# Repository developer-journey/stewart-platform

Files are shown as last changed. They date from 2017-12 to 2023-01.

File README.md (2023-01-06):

DISCONTINUATION OF PROJECT

This project will no longer be maintained by Intel.

Intel has ceased development and contributions including, but not limited to, maintenance, bug fixes, new releases, or updates, to this project.  

Intel no longer accepts patches to this project.

If you have an ongoing need to use this project, are interested in independently developing it, or would like to maintain patches for the open source software community, please create your own fork of this project.  
DISCONTINUATION OF PROJECT

This project will no longer be maintained by Intel.

Intel has ceased development and contributions including, but not limited to, maintenance, bug fixes, new releases, or updates, to this project.  

Intel no longer accepts patches to this project.

If you have an ongoing need to use this project, are interested in independently developing it, or would like to maintain patches for the open source software community, please create your own fork of this project.  
# Stewart platform source examples
Copyright (C) 2015-2017 Intel Corporation

## Overview

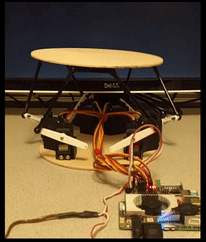
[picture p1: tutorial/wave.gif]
Do the Wave!


This directory provides **examples** that serve as supplimentary
material for the Developer Journey [1] to build a type of parallel 
robot called a Stewart platform [2].

1. https://01.org/developerjourney/stewart-platform
2. https://en.wikipedia.org/wiki/Stewart_platform

The examples contain software to:

* Communicate via i2c to a PCA9685
* Solve the Stewart platform to determine servo positions
* Utility functions for controlling the Stewat platform

To reduce dependencies, this program is not using MRAA to communicate
with the PCA9685.

## Stewart platform coordinate orientation

These routines work in a standaridzed world coordinate system (WCS)
where the XZ plane is the plane the Stewart platform is aligned to 
when no rotations are being performed (looking down on the Stewat 
platform.) The Y axis is aligned to the height of the Stewart platform 
axis (gravity).

The XZ plane is oriented such that the Z axis passes from between
servo 0|5 through the center of the platform (0, 0):

                                  z+
                                  ^
                                  |
                             .----+----.
                          2 /     |     \ 3
                           /      |      \
                        1 /       |(0,0,0)\ 4
                 x- <--- <--------+--------> ---> x+
                          \       |       /
                           \      |      /
                            \     |     /
                             `----+----'
                                0 | 5
                                  v
                    Top View      z-

## Building utilities

To build:

```bash
make
```

To test:
```bash
sudo bin/transform PITCH ROLL YAW X Y Z
```

For example:
```bash
sudo bin/transform 1 0 0  0 0 0
```

The above will rotate the platform one degree around the X axis.

## Piping data from STDIN

The `bin/transform` program can also read values from STDIN. When it
does so, however, it expects values to be provided in Axis-Angle form:

```bash
echo "0 1 0 3.5" | sudo bin/transform
```

The above will rotate the platform around the axis <0,1,0> by 3.5 degrees.

## Recording and playing back sequences

When piping data into transform, you can optionally record the sequence
of commands with timing information. You can then play that file back to
the application to repeat actions and movement sequences.

For example:
```bash
bin/joytrack /dev/input/js0 | bin/record MOVEMENTS | sudo bin/transform
```

You can then record a movement using your joystick (see the next section
for configuring a PlayStation 3 USB controller.) When you are done, 
press CTRL-C.

To play the file back:

```bash
bin/playback MOVEMENTS | sudo bin/transform
```

## Using a PS3 USB Controller

To use a PS3 USB controller to control the platform, you either need a
USB Bluetooth adapter or use it wired via the USB cable.

I have used the Rocketfish Micro USB Bluetooth adapter, which is 
supported in Ubuntu 16.04. You also need to pair the PS3 
controller with the system. You can follow the instructions here:

  http://qtsixa.sourceforge.net/manual.pdf

If you don't need/want to use the controller wirelessly, you can just
plug it into the USB port and open the joystick interface.

To do this, you only need the joystick package:

```bash
sudo apt install -y joystick
```

Once the PS3 controller is paired and recognized in the system (or if you
have any other joystick installed) you can use the program joytrack:

```bash
bin/joytrack /dev/input/js0 | sudo bin/transform
```

You can then control pitch and roll with left directional controller.

# Disclaimer

This project is released as reference code for research purposes. It is 
not an official Intel product, and the level of quality and support may 
not be as expected from an official product.

Feedback and contributions from the open source community are more than 
welcome.

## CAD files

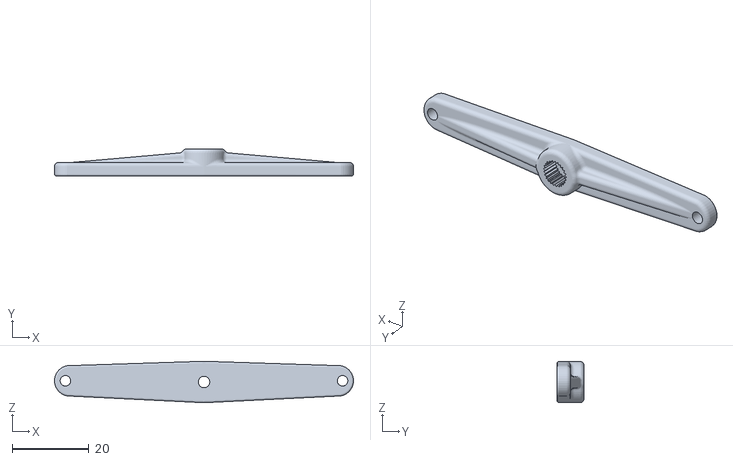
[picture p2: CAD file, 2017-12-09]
models/ServoArm.stl
78.0 x 7.00 x 10.8

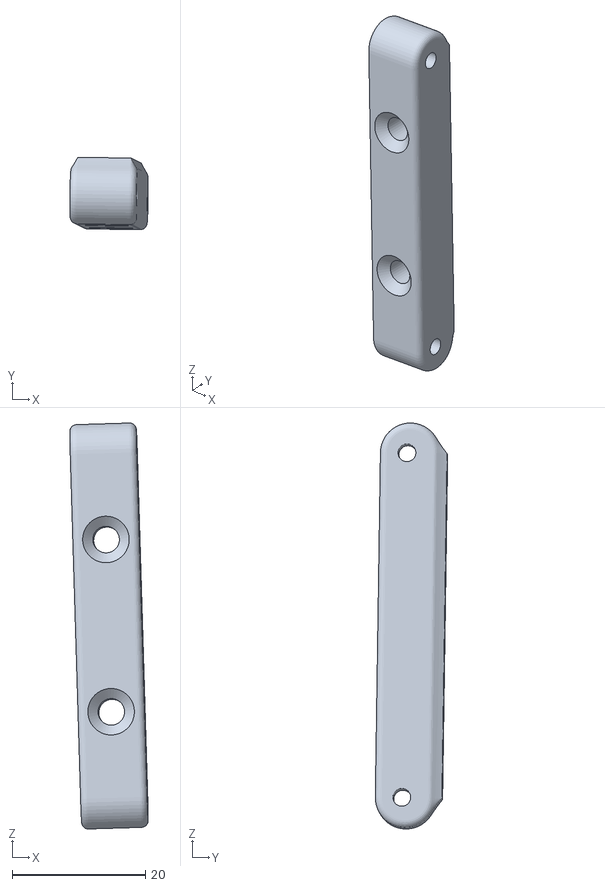
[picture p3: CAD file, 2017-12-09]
models/TopMount.stl
11.8 x 10.9 x 61.0

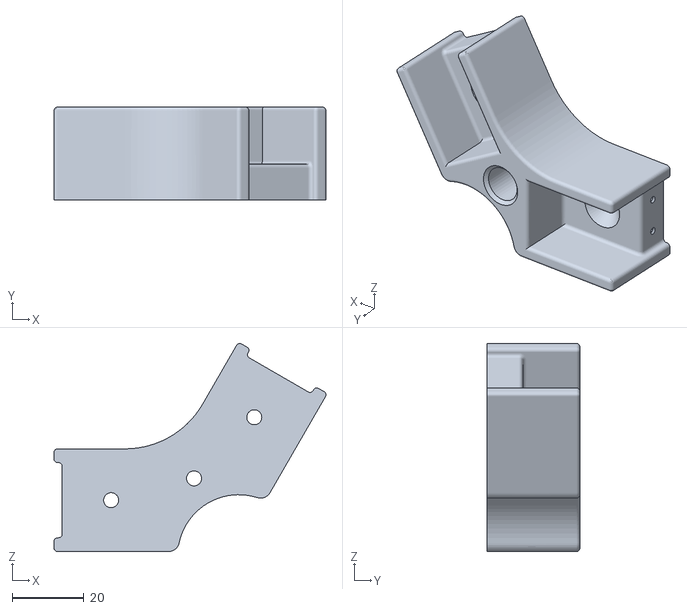
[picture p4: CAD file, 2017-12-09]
models/ServoMount.stl
76.0 x 26.0 x 58.2

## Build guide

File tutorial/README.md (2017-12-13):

---
title: Building a Stewart platform
author: James Ketrenos
license: cc-by-3.0
tags: robot, "stewart platform", "parallel robot"
---
# Introduction

Do the Wave!

Connecting the digital world to the physical world is exciting.

This guide provides you with the 3D models, information, and software to create your own Stewart platform.

## What is a Stewart platform?

Not familiar with a Stewart platform?

Stewart platforms have been used in vehicle and flight simulators, robotic skeleton assemblies, interactive marble maze solvers, and many other purposes.

A [Stewart platform](https://en.wikipedia.org/wiki/Stewart_platform) is a parallel robot with six degrees of freedom (6DOF).

The six degrees of freedom include movement in along three axis (X, Y, Z) as well as rotating in three directions (yaw, pitch, and roll.)

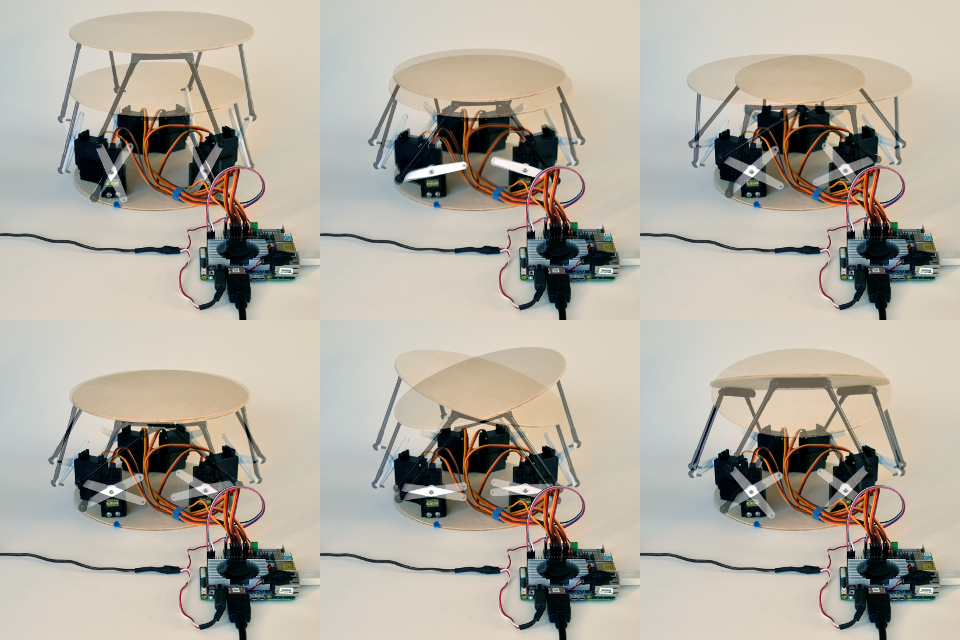
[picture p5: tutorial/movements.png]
Movement along Z, Y, and X axis. Rotation around Z-axis (Yaw), Y-axis (Pitch), and X-axis (Roll)


# Ingredients

Acquiring the parts is the most time consuming task. We've taken the guess work out by providing exact part descriptions and links to example products on the Internet.

There are three main categories of parts:

* The mechanical parts for the Stewart platform
* The electronics; wires, servos, breakout board
* The computer for controlling the Stewart platform

The total cost of all required parts, including the computer board, is ~$300US--having a 3D printer can save ~$66US.

## Mechanical parts

The mechanical parts needed for the Stewart platform include the top and bottom platforms, control rods to connect servos to the top platform, and the 3D printed components.

The total cost to acquire the mechanical parts is approximately $100US (only $34US if you print your own 3D printer.)

## Top and Base platform

| Qty | Name | Description | Est.$ |
|:---:|---|---|---|
|  2  | 8” MDF (or similar) wooden circles | Used as top and base plates. You can use a different size, however the board should be ⅛” ~ ¼” thick for rigidity and at least an 8” diameter [Amazon](https://www.amazon.com/gp/product/B00X6ATXHC) | $9 |
| 12  | M3 x 15mm Button Head Cap Screws (BHCS) | Helion HLNS1186 Button Head Cap Screws (BHCS) M3x15mm (10pcs) [Amazon](https://www.amazon.com/Helion-HLNS1186-Button-Screws-M3x15mm/dp/B01LXFZQ01) | $7 |
|  12 | #3 Phillips countersink screw with 8mm threading (10mm screw) | Used to connect control rod block and servo block platform boards. **NOTE**: Adjust the length of the countersunk screws to be the thickness of the MDF wooden circle + 5mm. If the screw is too long, it will stick through the wood; you can then grind/file the edge off. | $2 |

## Control rod components

| Qty | Name | Description | Est.$ |
|:---:|---|---|---|
| 12  | 10mm M3 threaded shaft (set screw) | Used to connect the ball joint to the connecting rod. [Amazon](https://www.amazon.com/RC4ZS0010-RC4WD-Threaded-Shafts-Screws/dp/B00A795L30) | $5 |
|  6  |65mm M3 aluminum standoff spacer|Used as the connecting rod. [Amazon](https://www.amazon.com/gp/product/B01NBXUD1E) | $5 |
| 12  |M3 straight ball joint|Pivot points between the connecting rods, the servos, and the platform. [Amazon](https://www.amazon.com/RC4WD-Medium-Straight-Plastic-Rod/dp/B009PBXIRW) | $5 |
| 12  |M3 lock nut (3/16" tall)|Used as a spacer between ball joints and mounted positions. You can also print spacers, or use washers, or anything you have that is ~3/16" thick. | $2 |

## 3D Printed Parts

There are a total of twelve parts to print. Three servo mounting blocks, six servo arms, and three top plate mounting brackets.

You can download and print the models yourselves, or print them via a 3rd party service. You can find 3D printers in your area via services like [Treat Stock](https://www.treatstock.com/3d-printable-models).

PLA is a sufficient material to use when printing.

### Servo mount

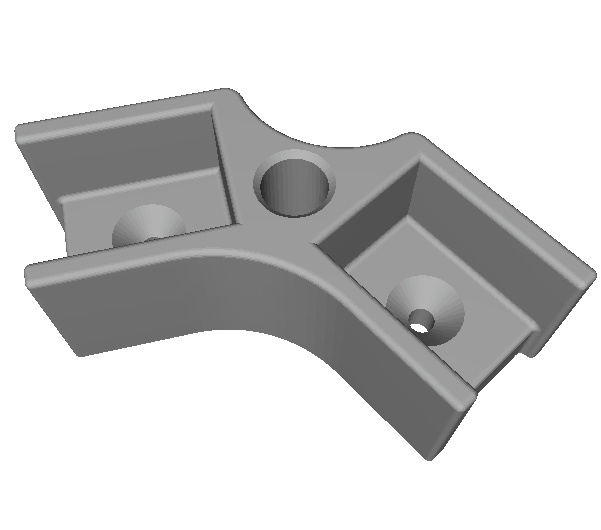
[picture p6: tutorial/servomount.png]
Sized to fit standard size servos, each block holds two servos. The servo blocks are designed to hold servos of depth 27.8mm, width 20mm.

Download the STL file [here](https://raw.githubusercontent.com/developer-journey/stewart-platform/master/models/ServoMount.stl).

|Qty|STL Link|Dimensions|Volume|
|:--:|:---|:---|:---|
|3|[Servo mount](https://raw.githubusercontent.com/developer-journey/stewart-platform/master/models/ServoMount.stl)|76mm x 26mm x 58mm|34,430mm ^ 3

### Servo arm

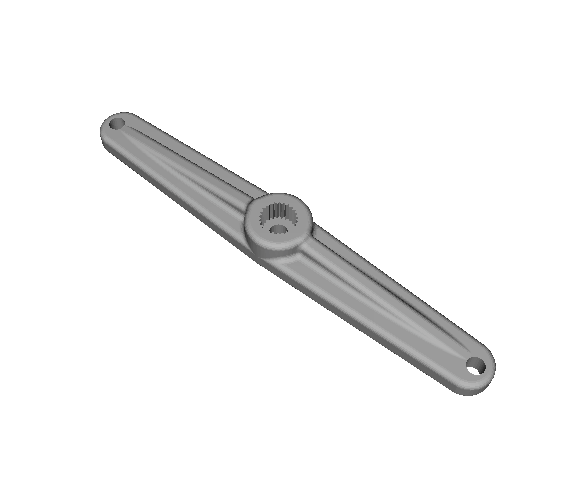
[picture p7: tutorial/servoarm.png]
Configured to fit 25-tooth servos (T25) the servo arms are 34mm from center to rod pivot point. The arms are bidirectional allowing you to adjust alignment after the servos have been set to their zero position.

Download the STL file [here](https://raw.githubusercontent.com/developer-journey/stewart-platform/master/models/ServoArm.stl).

|Qty|STL Link|Dimensions|Volume|
|:--:|:---|:---|:---|
|6|[Servo arm](https://raw.githubusercontent.com/developer-journey/stewart-platform/master/models/ServoArm.stl)|78mm x 7mm x 11mm|2,794mm ^ 3|

### Top mount

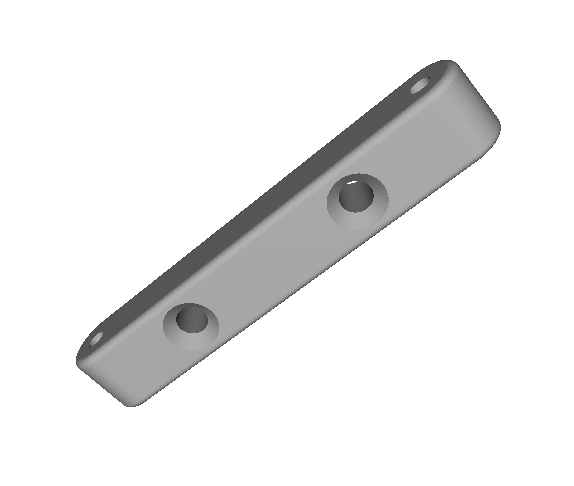
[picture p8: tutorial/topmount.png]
Mounted to the top plate, the control rod assemblies connect to these.

The holes are countersunk on one side -- make sure that side faces away from the board when mounting (so the screws can be flush.)

Download the STL file [here](https://raw.githubusercontent.com/developer-journey/stewart-platform/master/models/TopMount.stl).

|Qty|STL Link|Dimensions|Volume|
|:--:|:---|:---|:---|
|3|[Top mount](https://raw.githubusercontent.com/developer-journey/stewart-platform/master/models/TopMount.stl)|12mm x 11mm x 61mm|5,306mm ^ 3

## Electronics

The electronics consist of the UP board, a PWM breakout board, wires, connectors, power supply, and the hobby servos. 

The total cost of electronics is approximately $200US.

Items you may already have (HDMI cables, keyboard, etc.) are not included in the price estimate.

| Qty | Name | Description | Est.$ |
|:---:|---|---|---|
|  6  | Standard hobby servo | Higher quality servos yield a more stable platform; that said, most of my platforms are built using the cheapest servos I can find. **NOTE:** The 3D models for this recipe are designed for standard hobby sized servos with a T25 spline, a depth of 27.8mm, and a width of 20mm. | 6x$9=$54 |
|  1  | PCA9685 breakout board | I2C based board that provides 16 PWM channels. The Stewart platform only needs 6 of those channels--leaving 10 available for LEDs and other features! Different vendors sell the PCA9685 breakout boards with all parts pre-soldered. [Amazon](https://www.amazon.com/dp/B014KTSMLA) | $12 |
|  4  | Female to female jumper wires | Used to connect GND, VCC, I2C SDA, and I2C SCL from the UP’s 40-pin HAT to the PCA9685 board | |
|  1  | 5V 10A DC power source | Used to provide power to the servos controlled by the PCA9685. Powering six servos will pull more current than a lower amperage power adapter can supply.  [Amazon](https://www.amazon.com/ALITOVE-Adapter-Converter-Charger-5-5x2-1mm/dp/B01M0KLECZ) | $21 |
|  1  | Female barrel plug connector | Used to create a connector for the 5V 10A DC power supply [Amazon](https://www.amazon.com/ALITOVE-Adapter-Converter-Charger-5-5x2-1mm/dp/B01M0KLECZ). This comes with the 10A power supply linked above. If you want to get one by itself, see [Amazon](https://www.amazon.com/CableWholesales-Female-Power-Terminal-Adapter/dp/B009H0TJ88) | $0 |
|  2  | 12” length of 18AWG or lower | Used to connect the female barrel plug to the PCA9685’s DC V+ and GND terminals. | |

## UP board

You need an UP board running Ubuntu 16.04 or newer for this recipe. If you do not have an UP board, below are the components you need. For instructions on installing Ubuntu 16.04 onto the UP board, you can follow Steps 1 through 5 of [Intel RealSense Robotic Development Kit](https://01.org/developerjourney/recipe/intel-realsense-robotic-development-kit).

| Qty | Name | Description | Est.$ |
|:---:|---|---|---|
|  1  | UP board  | Used to solve the Stewart platform equations, control the servos, and provide additional compute resources for custom features. [up-shop](https://up-shop.org/up-boards/2-up-board-2gb-16-gb-emmc-memory.html) | $99 |
|  1  | 5V 4A power supply for the UP board | Provides power to the UP board. [up-shop](https://up-shop.org/up-peripherals/65-dc-power-adapter-for-up-board-eu-plug.html) The 5V 10A supply (in the prior section) may is typically enough to power both the servos **and** the UP board, however using a single power supply requires you to build a Y-connector. | $11 |
|  1  | USB Keyboard | Used for input to the UP board | |
|  1  | HDMI cable | Used for the UP board | |
|  1  | HDMI monitor | Used for the UP board | |
|  1  | 8G+ USB flash drive | Used for installing Ubuntu  onto the UP board | | 
|  1  | (optional) USB mouse | If you want to use a GUI with the UP, a mouse makes it easier. | |
|  1  | (optional) Ethernet cable | Used to provide network to the UP board | |

## Tools

The following tools are used to assemble the pieces:

| Name | Description |
|---|---|
| 5/64” drill bit | Used to make pilot holes for wood screws in top and base platform boards. |
| Drill | Use with the drill bit. |
| 2mm allen wrench | Used to install cap screws into servo assemblies |
| Philips screw driver | Used to install servos into servo blocks, servo arm screw, and to tighten power leads into power terminals. |
| Wire stripper or utility knife | Used to strip the wires from the 5V 10A DC power supply |

# Step: Assemble six control rods

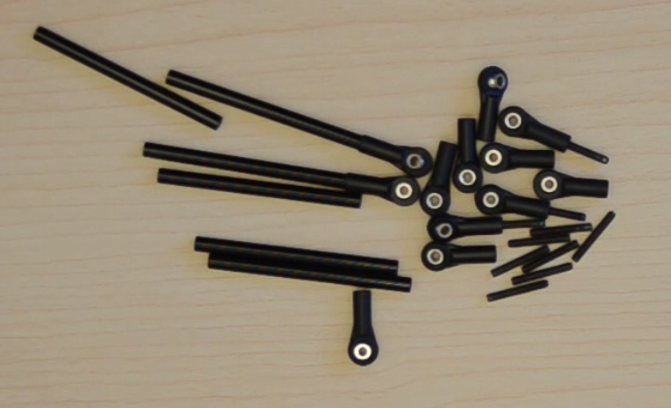
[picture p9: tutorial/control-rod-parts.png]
Parts used in this step


Assemble six control rods. For each rod, thread one 10mm M3 threaded rod into each of the M3 ball joints until the threaded rod is approximately half way into the joint. Then screw the other half into the 65mm M3 standoff. Repeat on both ends of the standoff.

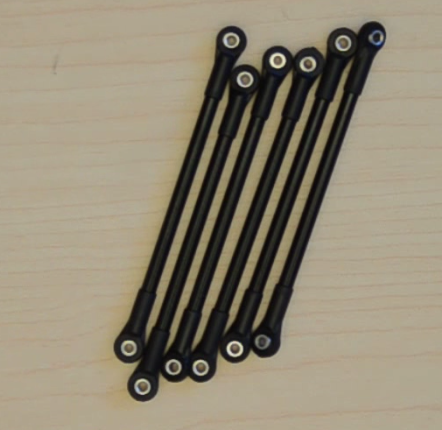
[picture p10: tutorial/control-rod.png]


**NOTE:** If you screw the threaded rod into the standoff first, there may not be enough friction between the threads and the standoff to successfully screw the second half of the rod into the ball joint.

# Step: Attach control rod assembly to top platform bracket

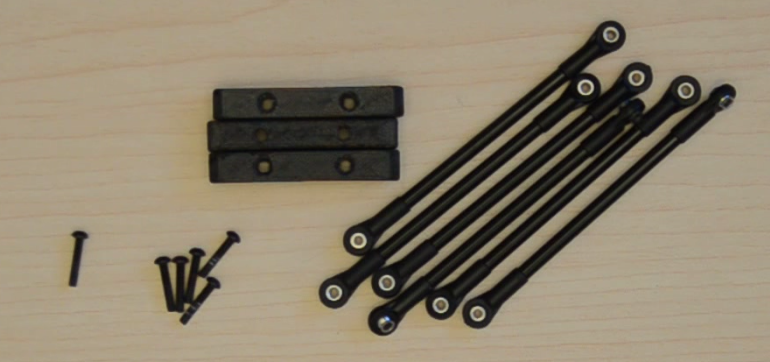
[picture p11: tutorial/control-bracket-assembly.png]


Use six 15mm button head screws to attach the control rods to the three top platform brackets, placing a 3/16" thick spacer (3M lock nut) between the ball joint and the platform bracket (not shown in image).

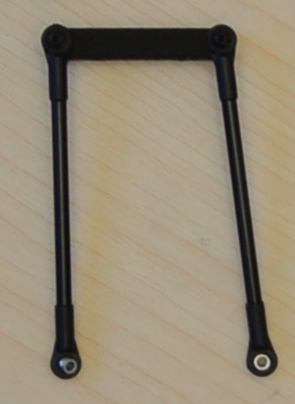
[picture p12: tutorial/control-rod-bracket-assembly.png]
Control rods connected to top platform bracket


# Step: Attach servo arm to control rod bracket assembly

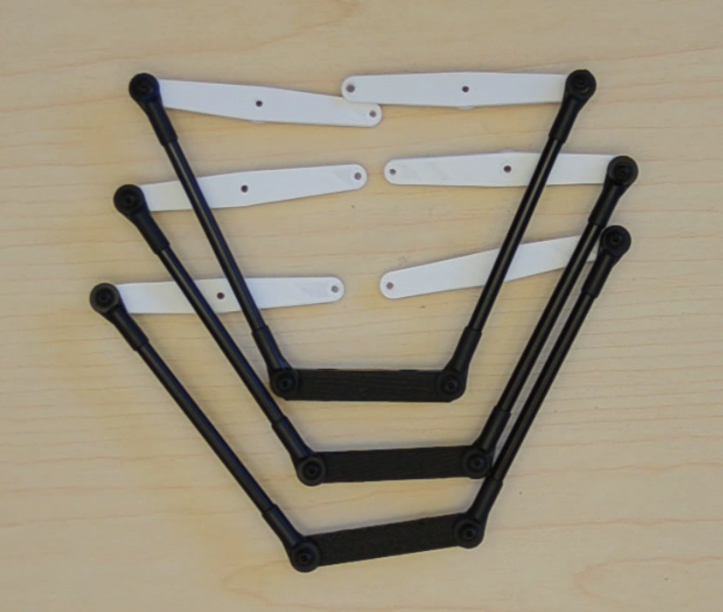
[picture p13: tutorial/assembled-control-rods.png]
Assembled servo arm control rod bracket assemblies.
 Next attach servo arms to the the control rod bracket assemblies using six 15mm button screws.  Place a 3/16" thick spacer (3M lock nut) between the ball joint and the servo arm (not shown in image).

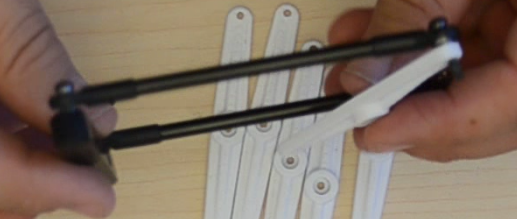
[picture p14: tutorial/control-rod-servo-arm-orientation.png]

Be sure to orient the servo arm correctly as seen in this image.

**NOTE**: The spacer is not shown in this image.

# Step: Drill top and base platforms

Print out the top and bottom platform templates.

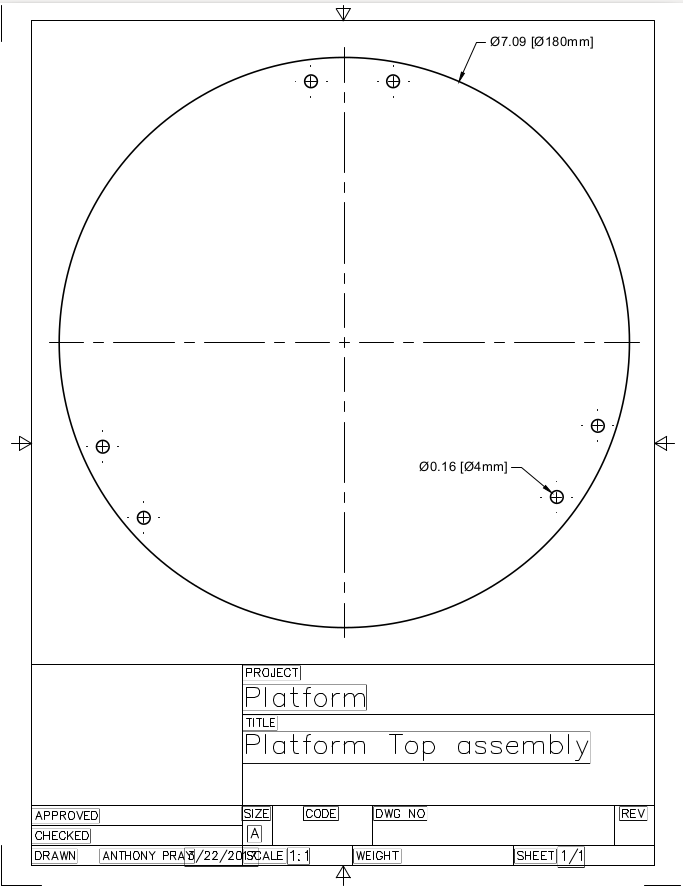
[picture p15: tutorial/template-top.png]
Top platform


Link to PDF: [top-platform.pdf](https://raw.githubusercontent.com/developer-journey/stewart-platform/master/models/top-platform.pdf)

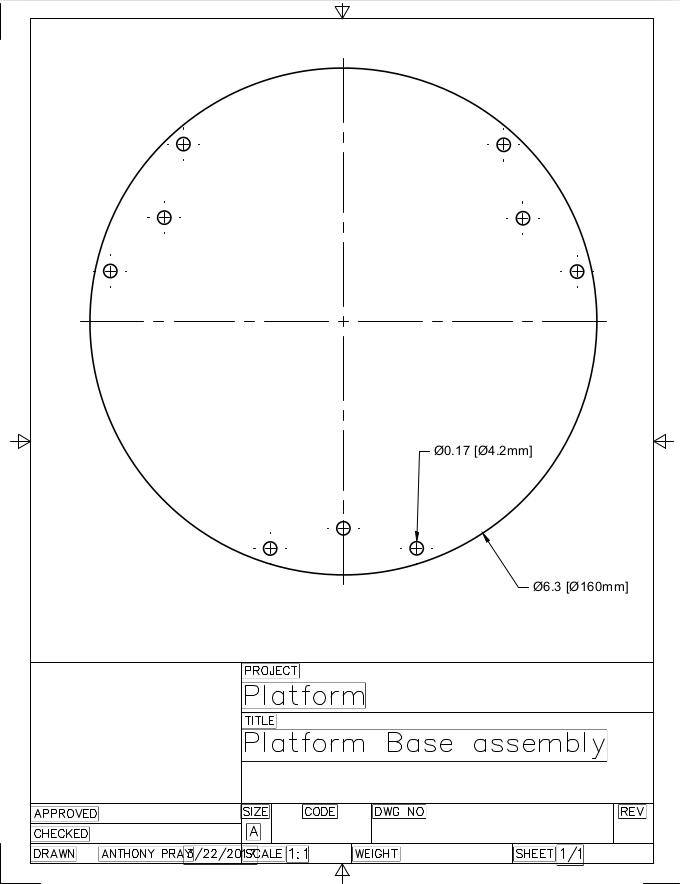
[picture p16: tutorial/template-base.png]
Base platform

Link to PDF: [base-platform.pdf](https://raw.githubusercontent.com/developer-journey/stewart-platform/master/models/base-platform.pdf)

Print the templates from the PDFs on 8.5” x 11” paper in portrait mode -- and turn off all margins, scaling, and resizing. You want the edge guide marks to be at the edge of the printed sheet--if you scale the printouts in any way, the holes you drill won’t match the 3D printed parts.

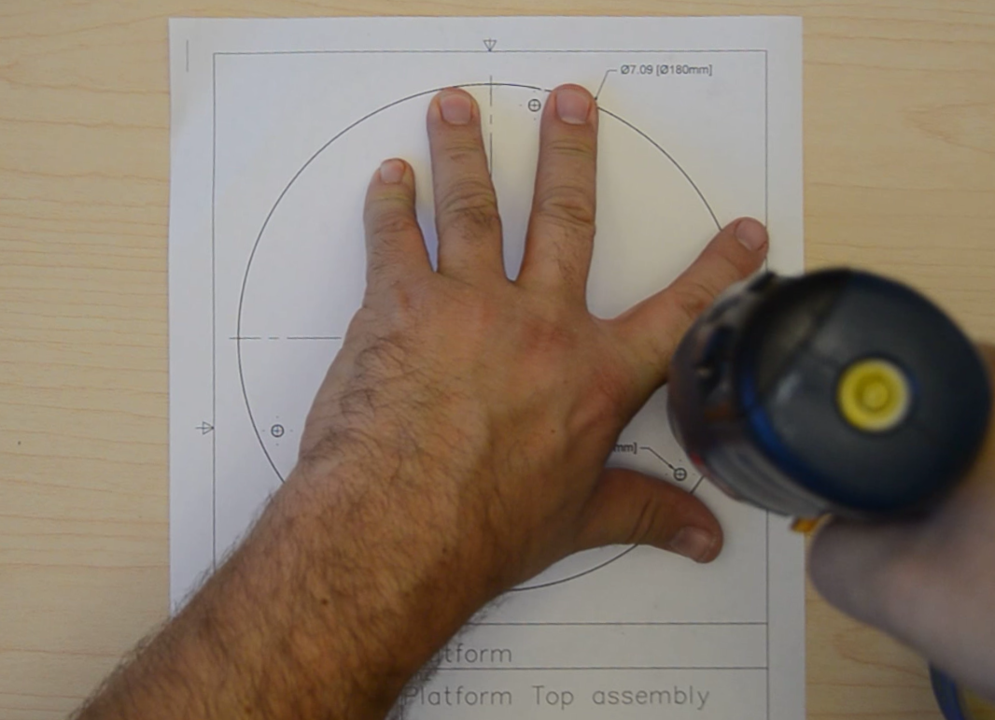
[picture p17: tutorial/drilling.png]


**NOTE:** The board edge in the printout is to help in centering the paper to the board and may not be the same size as your board.

*Tip:* To prevent slipping while drilling, use tape to affix the board to the back of top platform assembly. 

You can use a screwdriver to tap an indentation on the exact center points to help prevent the drill from wandering.

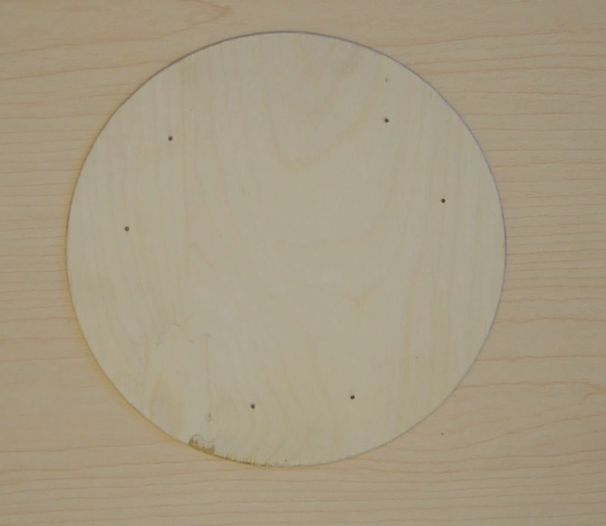
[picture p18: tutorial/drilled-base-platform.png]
When drilling the base platform, you only need to drill the six holes along the edge--the third hole is optional.

# Step: Attach control rod assembly to top platform

Using six of the wood screws, attach the three control rod assemblies to the top platform. 

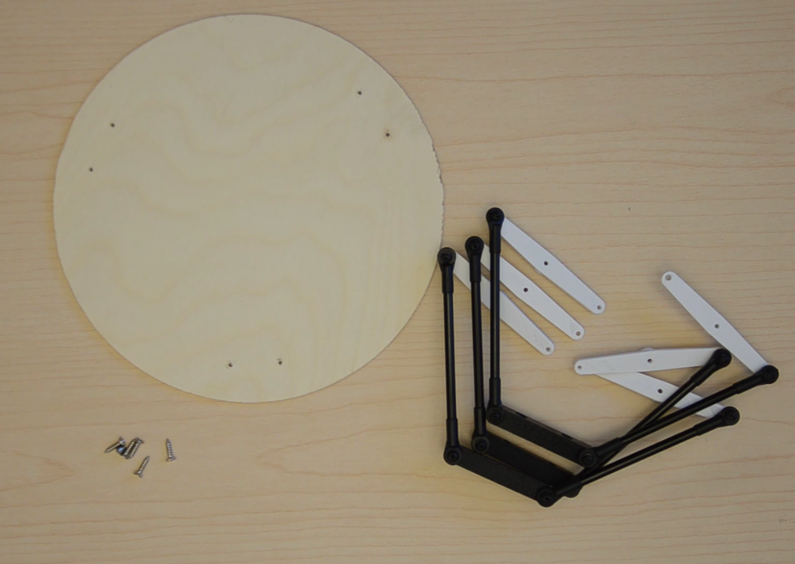
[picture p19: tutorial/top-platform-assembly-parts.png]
Parts used in this step


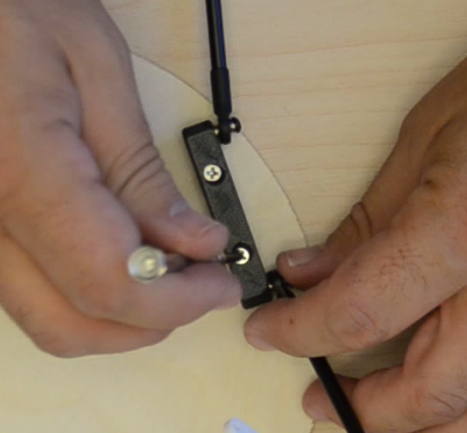
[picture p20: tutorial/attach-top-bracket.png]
The control rods should be on the outside edge of the circle.

**NOTE:** Only one side of each mounting block has countersunk holes.

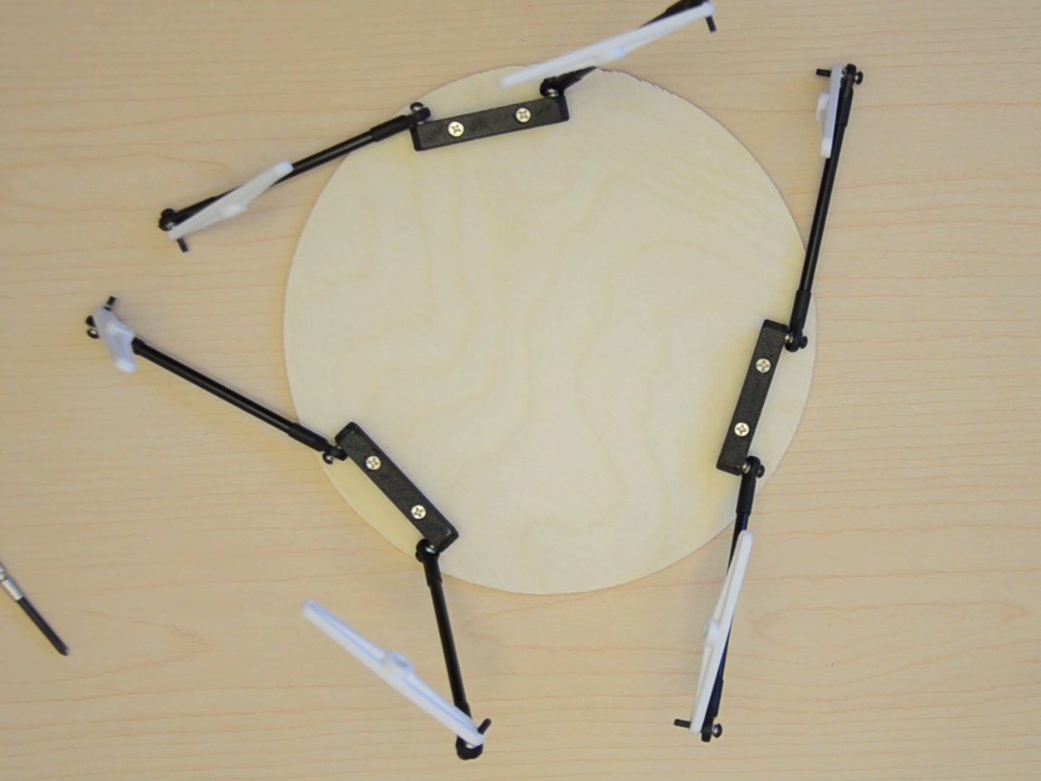
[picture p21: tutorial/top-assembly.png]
Assembled top platform


If your screws are too long and stick through the board, use a file to grind down the tip of the screw.

For added strength, you can place a drop of wood glue at each pilot hole prior to affixing the bracket to the top platform.

# Step: Attach servo blocks to bottom platform

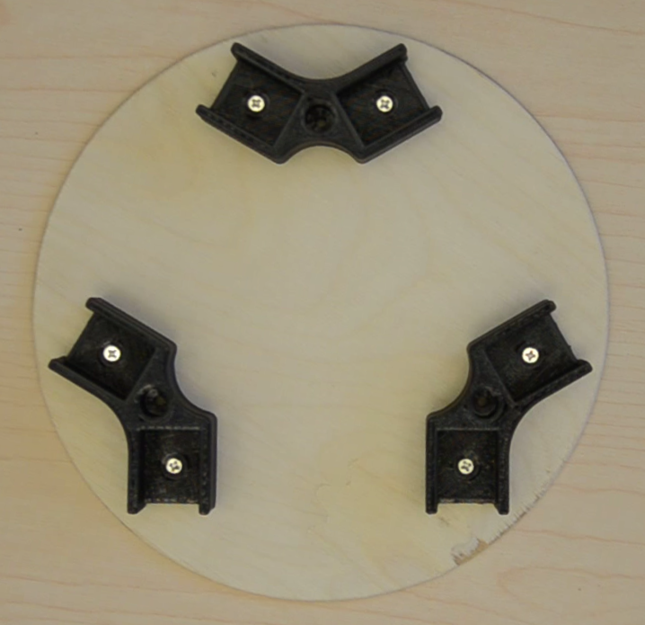
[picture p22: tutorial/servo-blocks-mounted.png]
Assembled base platform


Using six wood screws, attach the three servo blocks to the base platform.

If the screws are longer than the thickness of your base platform, file off any of the screw protruding from the bottom of the base.

# Step: Attach servos to servo blocks

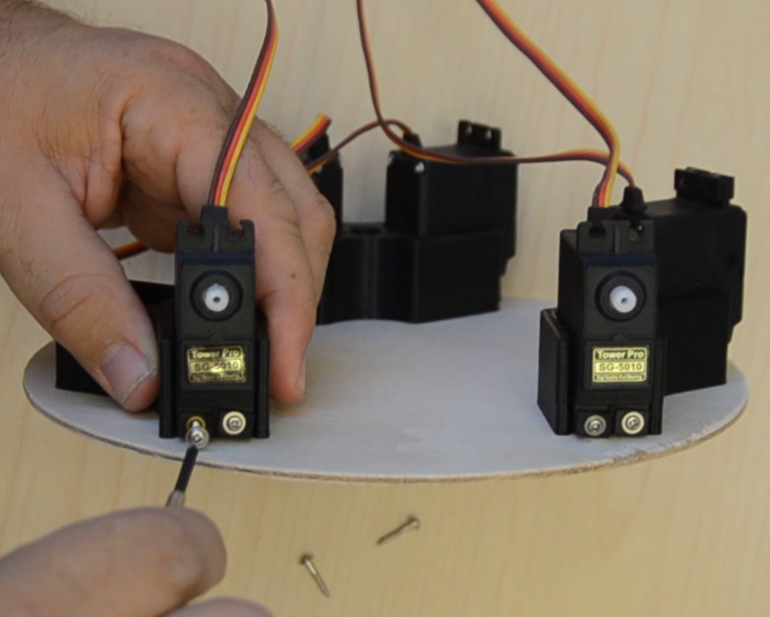
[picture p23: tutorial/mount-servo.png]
Use the screws that came with your servo to attach the six servos to the three mounting blocks on the base platform.

### Number the servos

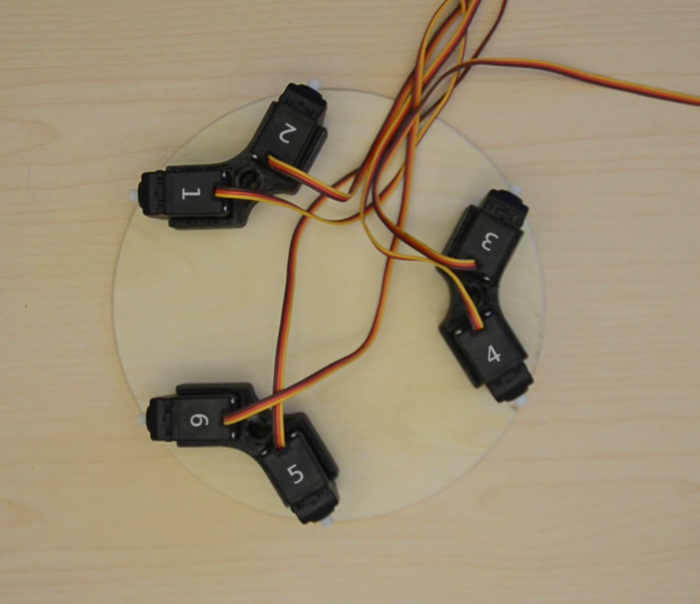
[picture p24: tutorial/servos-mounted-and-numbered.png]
After you have installed the servos, mark servo #1 so you can refer to it later. When calibrating  and connecting the servos, they are referred to via their clockwise numbering.

# Step: Attach the two platforms

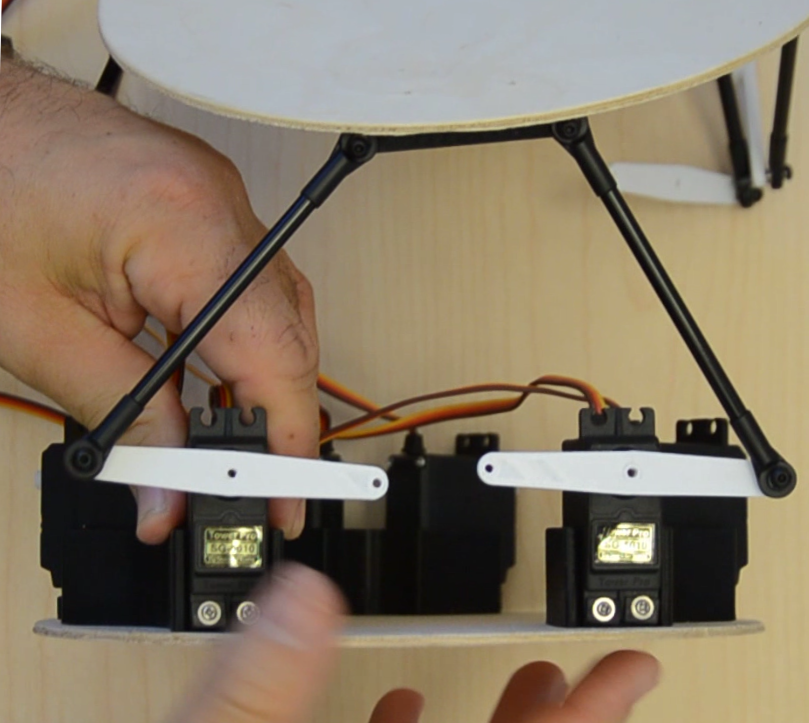
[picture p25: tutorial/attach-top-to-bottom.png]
Align the top platform such that the control rod mounting bracket is parallel to the face of two servos. Attach the servo arms with the control rods on opposite sides as seen in this image. Rotate and do the same for the remaining four servos.

**Do not** screw in the servo arms into the servos at this time. When the Stewart platform is initialized, all of the servos will reset to their zero position and you may need to make adjustments

# Step: Attach servo wires to PCA9685

Next attach the six servos to the PCA9685 breakout board.

This tutorial is using Tower Pro SG-5010 servos. Those servos use the following color scheme:

| Color | Pin |
|:---|:----|
|YELLOW | PWM |
|RED | V+  |
|BROWN  | GND |

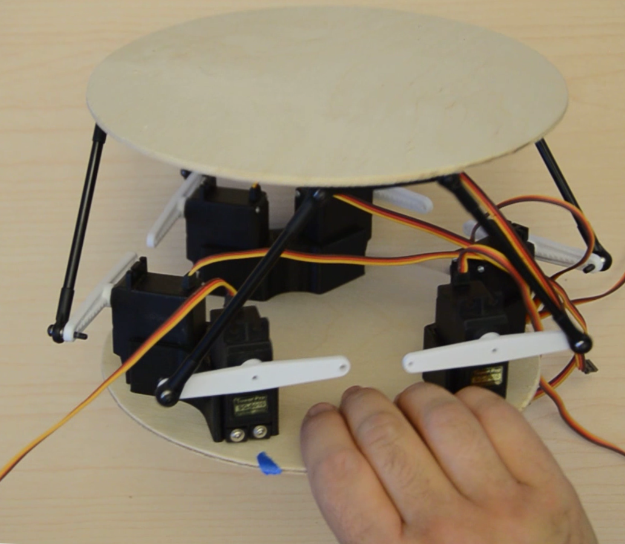
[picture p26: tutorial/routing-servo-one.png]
Routing servo #1
Servo #1 (marked with blue tape) is being connected to PCA9685 PWM channel 0.

Starting with servo #1, route the servo wire out of the Stewart platform and connect it to the PCA9685 board, beginning with channel 0. 

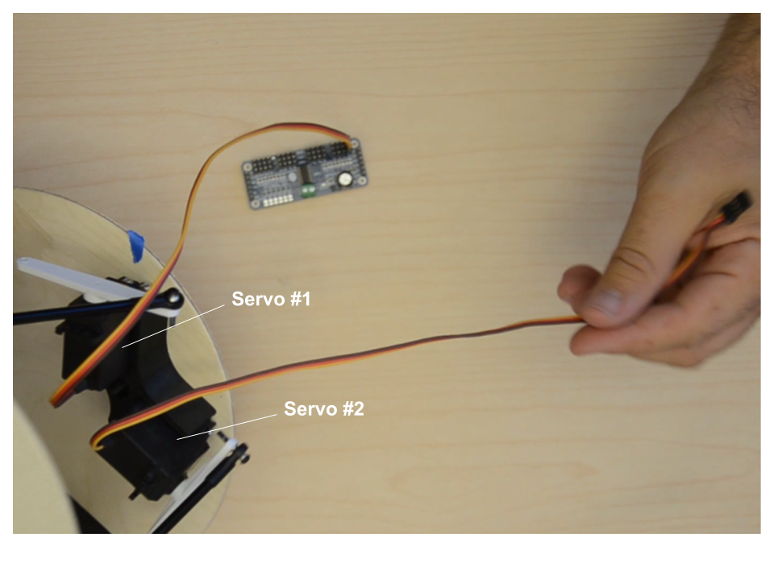
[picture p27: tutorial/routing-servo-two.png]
Routing servo #2
Continue in a clockwise direction around the Stewart platform, routing the wires through the same space between servos on the platform.  Attach each servo to the next open channel on the PCA9685.

# Step: Attach PCA9685 to UP board

The PCA9685 is controlled using a two wire protocol for control called I2C. In addition to the two wires for I2C, the PCA9685 needs to be connected to ground and 3.3V.

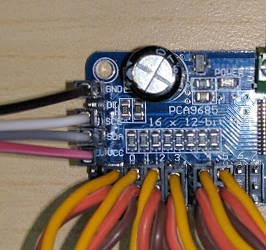
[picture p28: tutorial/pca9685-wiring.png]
Connect the four jumper wires to PCA9685’s GND, SCL, SDA, and VCC pins.

In the following image BLACK is connected to GND, WHITE is connected to SCL, GRAY is connected to SDA, and RED is connected to VCC.

On the UP board, connect GND (Black) to [pin 6](https://board-explorer.github.io/board-explorer/#up-board/HATPin6), VCC (Red) to [pin 1](https://board-explorer.github.io/board-explorer/#up-board/HATPin1), SDA (Gray) to [pin 3](https://board-explorer.github.io/board-explorer/#up-board/HATPin3), and SCL (White) to [pin 5](https://board-explorer.github.io/board-explorer/#up-board/HATPin5):

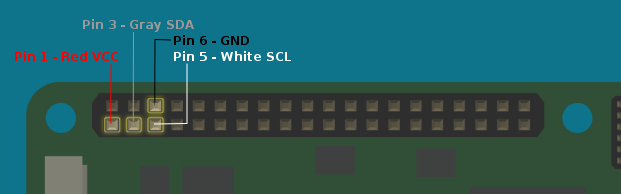
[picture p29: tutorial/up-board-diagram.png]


See [Board Explorer: UP](https://board-explorer.github.io/board-explorer/#up-board/HATPin1,HATPin3,HATPin5,HATPin6) for an interactive view of the UP board’s pin headers.

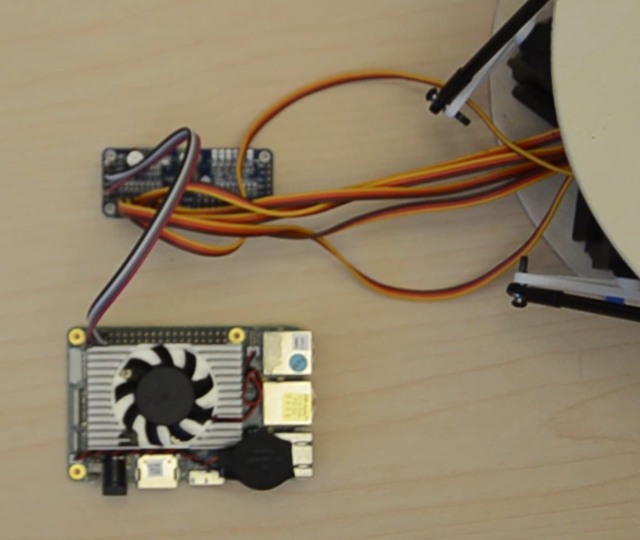
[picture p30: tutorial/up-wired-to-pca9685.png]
UP board connected to PCA9685
 Once all of the servos and the I2C wires have been connected to the UP board, it should look like the image here.

# Step: Wire DC terminal to the PCA9685

Attach one 12” length of 18AWG wire to the PCA9685’s GND terminal and the other wire to the PCA9685’s V+ terminal. Use a small phillips screwdriver to make the connection secure.

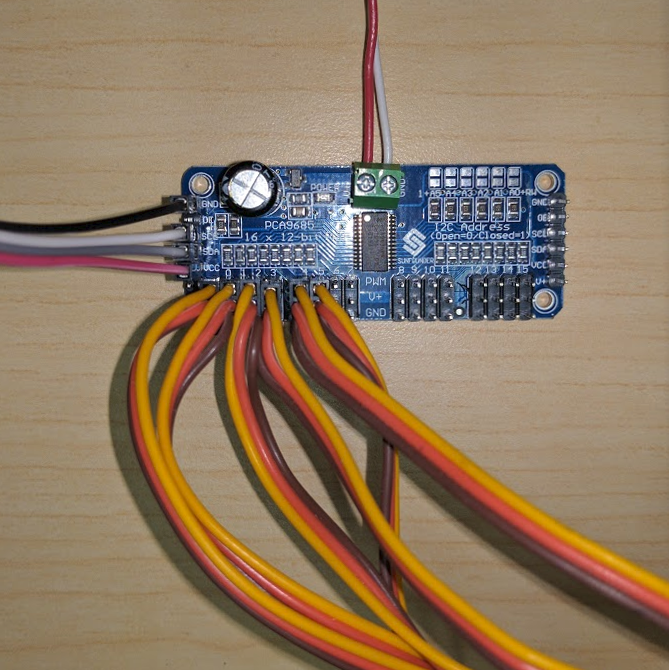
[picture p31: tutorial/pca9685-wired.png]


Attach the other side of the wires to the female barrel plug connector. Make sure the PCA9685’s V+ terminal is connected to the + terminal on the barrel connector.

**Do not plug the power supply into an outlet yet.**

## Step: Connect peripherals to UP board

Connect the USB keyboard, HDMI cable, and DC adapter. **Do not plug the power supply into an outlet yet.**

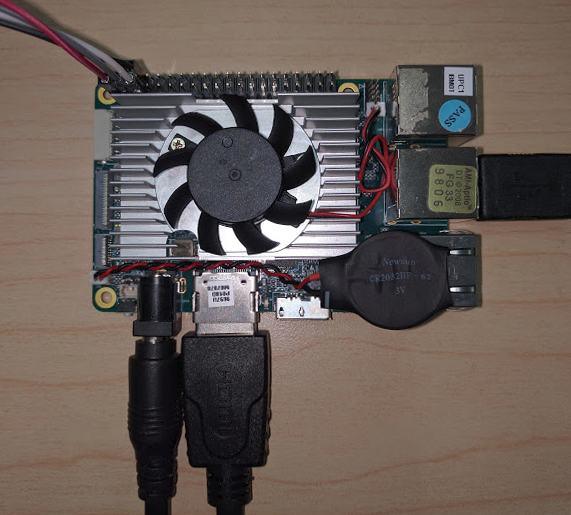
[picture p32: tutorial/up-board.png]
Power, HDMI, and USB keyboard connected to UP board


# Step: Power it up!

Remove all of your tools from the vicinity of the UP board and PCA9685 breakout board.

Re-check that all of your connections are still good, and that no wires have come loose. You are now ready to supply power to the UP board and PCA9685.

Using a splitter, a single 5V 10A adapter provides power to both the UP board and PCA9685.

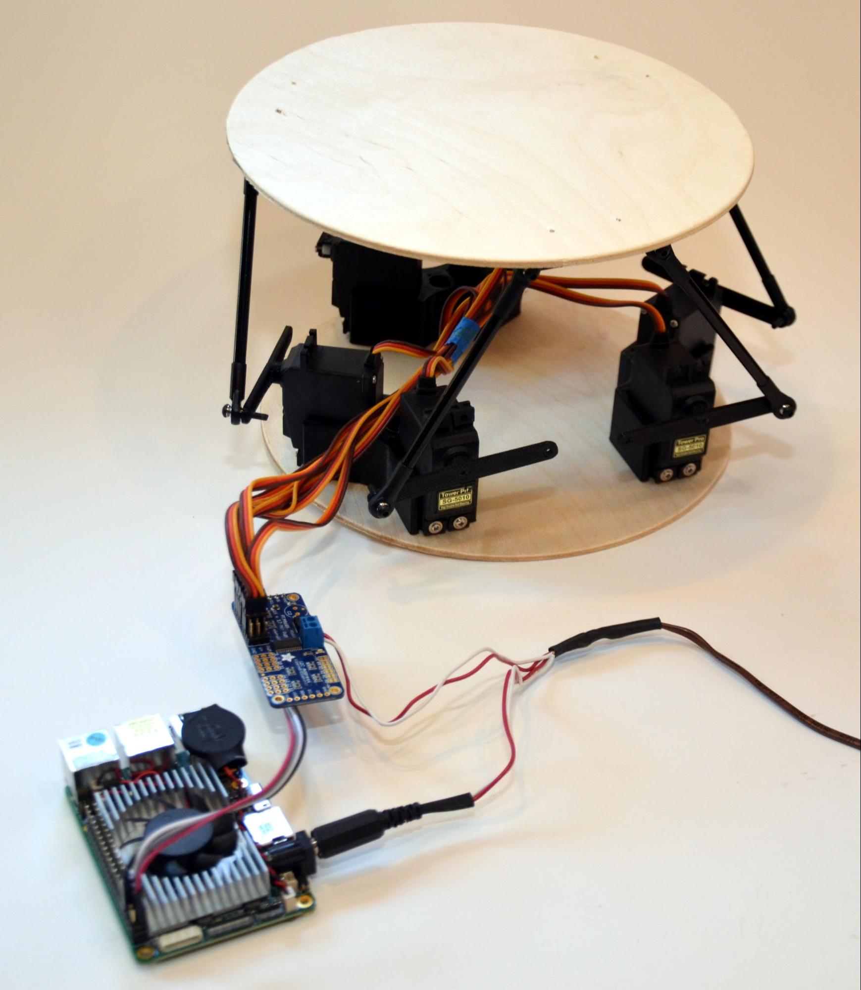
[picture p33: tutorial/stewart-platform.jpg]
 Once power is applied, the UP board’s power LED should illuminate. Similarly, an LED should illuminate on the PCA9685 breakout board.

If you have not already installed a Linux operating system on the UP board, you can follow Steps 1 through 5 of [Intel RealSense Robotic Development Kit](https://01.org/developerjourney/recipe/intel-realsense-robotic-development-kit) to get Ubuntu 16.04 installed.

This will prepare your UP board to initialize the Stewart platform during the final assembly steps.

# Step: Initialize the servos

Prior to finalizing the Stewart platform by installing the screw into servo arms, the servos must be initialized to zero. 

To do that, use the ‘transform’ utility (provided via the stewart-platform repository) to initialize all six servos to zero.

## Install build tools and git

To build the Stewart platform project, the UP board needs to have the build tools installed.

From a command terminal on the UP board, perform the following steps:

```bash
sudo apt install -y build-essential git
```

## Clone and build the Stewart platform project

```bash
cd ~
git clone https://github.com/developer-journey/stewart-platform.git
cd stewart-platform
make
```

## Initialize the servos

```bash
cd ~/stewart-platform
sudo bin/transform 0 0 0  0 0 0
```

The servos should all move to their **internal** zero position. 

If the software can not connect to the PCA9685 device, it will output an error. If you encounter an error, make sure that you are running the ubilinux kernel provided by UP board (as described in the installation tutorial)--without that kernel, the 40-pin HAT is not enabled.

## Adjust the servos to zero position

Once the servos are powered initialized using `transform 0 0 0  0 0 0`, you can adjust the servo arms as necessary, then secure them using the scews provided with your servo.

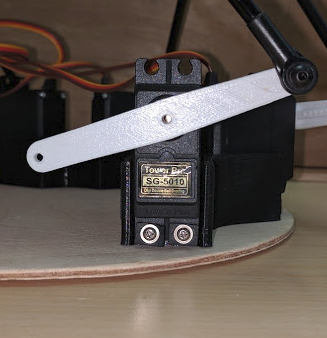
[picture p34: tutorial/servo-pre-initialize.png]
Servo arm needs adjustment
 After initialization, servo is at zero and servo arm is misaligned.  

While servo is at zero, remove and reset the servo arm to horizontal.

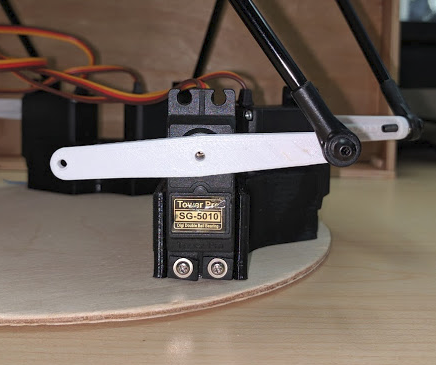
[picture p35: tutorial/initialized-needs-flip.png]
Arm needs to be flipped
 **Note** the servo arm may not be able to be exactly horizontal. 

The servo arms have 25 teeth in them to grip the servo. This allows them to be offset by one half of a tooth to provide better alignment by rotating the servo arm 180°.

To remedy, unscrew the control rod from the servo arm, rotate the servo arm 180°, and see if it can mount closer to horizontally. Pick whichever is closest to horizontal. Re-attach control rod.

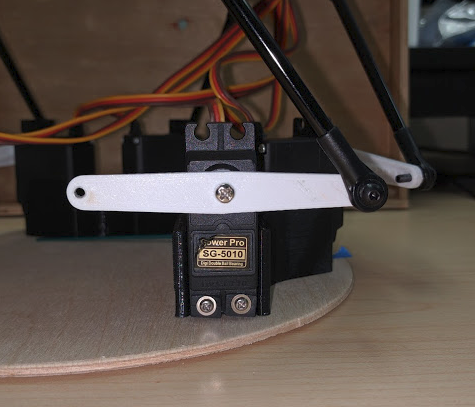
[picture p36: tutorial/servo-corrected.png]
Horizontal at zero
Arm is now horizontal at servo 0 position. Install the servo arm set screw to fix the arm at this position.

# Step: Put the platform through its motions

You are now ready to control the Stewart platform!

Boot the UP board back up and use the transform routine to test the performance of the platform.

The ‘transform’ utility allows you to move the platform in three dimensions (the first three parameters) in millimeters, and to tilt the platform in three angles (the last three parameters) in degrees.

```bash
cd stewart-platform
# center the platform
sudo bin/transform 0 0 0  0 0 0
# roll forward / backward
sudo bin/transform 5 0 0  0 0 0
sudo bin/transform -5 0 0  0 0 0
# pitch left / right
sudo bin/transform 0 -5 0  0 0 0
sudo bin/transform 0 5 0  0 0 0
# yaw clockwise / counter-clockwise
sudo bin/transform 0 0 5  0 0 0
sudo bin/transform 0 0 -5  0 0 0
```

Experiment with all of the parameters.

View `stewart-platform/README.md` for additional information and utilities provided with the Stewart platform project.

# Step: Do the wave!

The `transform` utility can either take input from the command line, or via `stdin`.
 Included in the [stewart-platform project](https://github.com/developer-journey/stewart-platform) is a NodeJS application which will output to stdout command for transform.


```bash
sudo apt install -y nodejs
cd ~
node node/wave | sudo bin/transform
```

# Congratulations!

Congratulations! You have built a functional Stewart platform. Tell us how it went by leaving a comment.

If you have any problems, you can file an issue with the [Stewart platform](https://github.com/developer-journey/stewart-platform/issues) project on GitHub.

# What's coming next?

We're working on the next article using the Stewart platform...

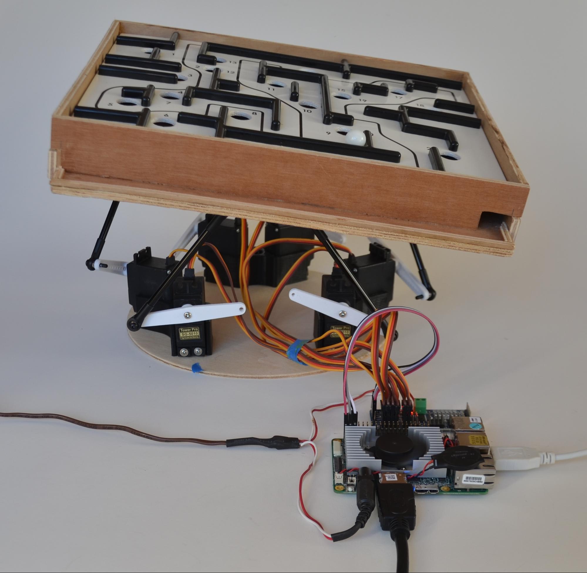
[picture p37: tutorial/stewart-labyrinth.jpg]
Play labyrinth
 Using a PS4 controller you can play the labyrinth marble game.

Add a camera, and you can now experiment with vision processing, machine learning, and artificial intelligence to have the computer play itself!

# Appendix B: Adjusting the Stewart platform dimensions

The software to control the Stewart platform is pre-programmed with dimensions that match the 3D printed models.

If you modify the models to fit different servos or arrangements, you may need to modify the `config.h` file and re-build.

The images below are intended help you better understand which values to measure:

## SERVO_ARM_LENGTH

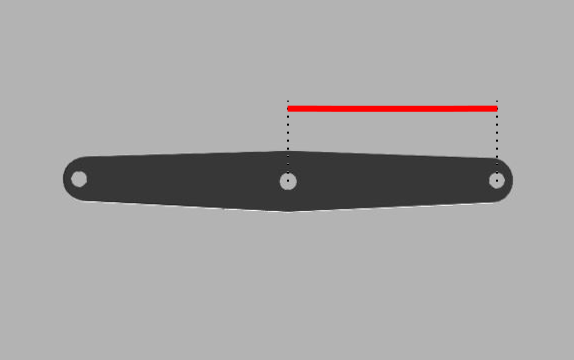
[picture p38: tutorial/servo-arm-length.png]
Servo arm length


Servo arm length in inches from center to ball joint pivot.

Defaults to 1 7/16”

## CONTROL_ROD_LENGTH

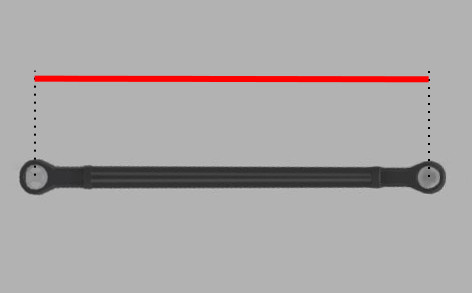
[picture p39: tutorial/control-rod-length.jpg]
Control rod length


Control rod length in inches from ball joint center to center.

Defaults to 4 1/16”

## PLATFORM_HEIGHT

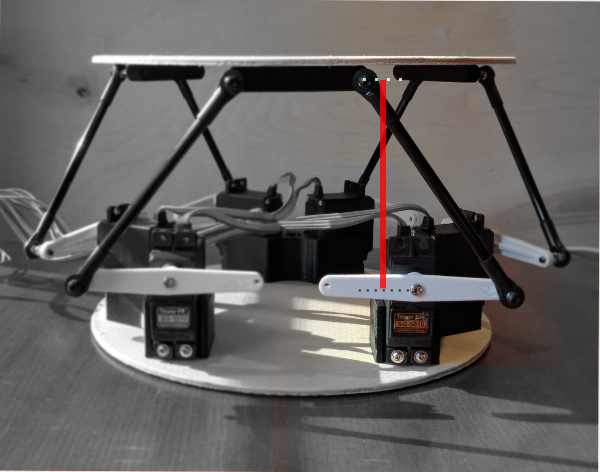
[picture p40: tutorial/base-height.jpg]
Platform height


With servos at 0 position, vertical distance servo axis to the top of the control rod’s ball joint (in the above image, it is the green line.)

This is used as Z coordinate in the effector_pos.

Defaults to 3 5/16”

**NOTE**: This is a value that could be calculated automatically based on the triangles formed from the servo arm, control rod length, and the top and bottom radii. However I haven't done that yet, so the code must define it.

## EFFECTOR_RADIUS

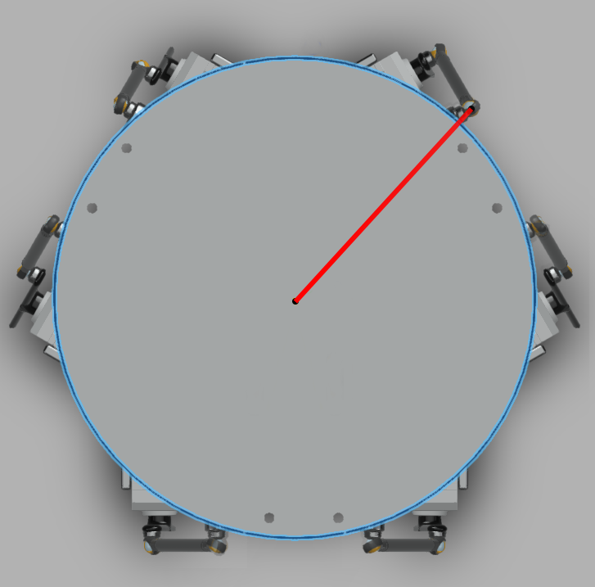
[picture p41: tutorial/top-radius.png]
Effector (top platform) radius


Center of top platform to effector ball joint connector center in inches.

Defaults to 3.949”

## BASE_RADIUS

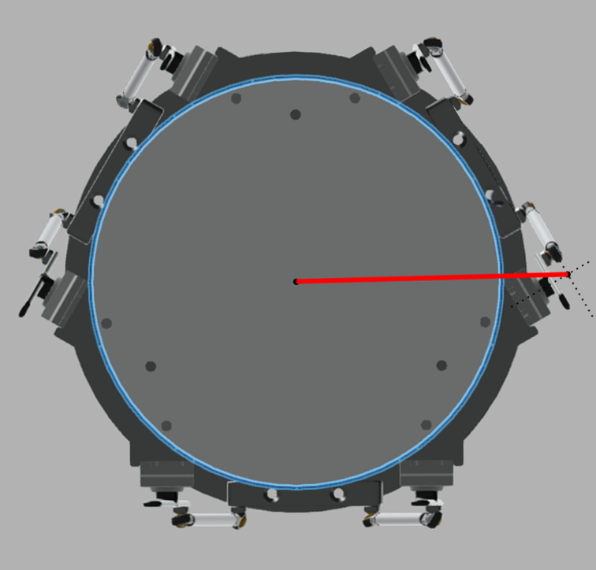
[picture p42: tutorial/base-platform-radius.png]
Base radius


Center of base platform to control rod *pivot** point along servo arm axis, in inches.

Defaults to 3 13/16”

**NOTE**: This is not just the measurement to the servo arm, but to where the plane of the control rod's ball joint intersects with the servo arm axis.

## THETA_BASE

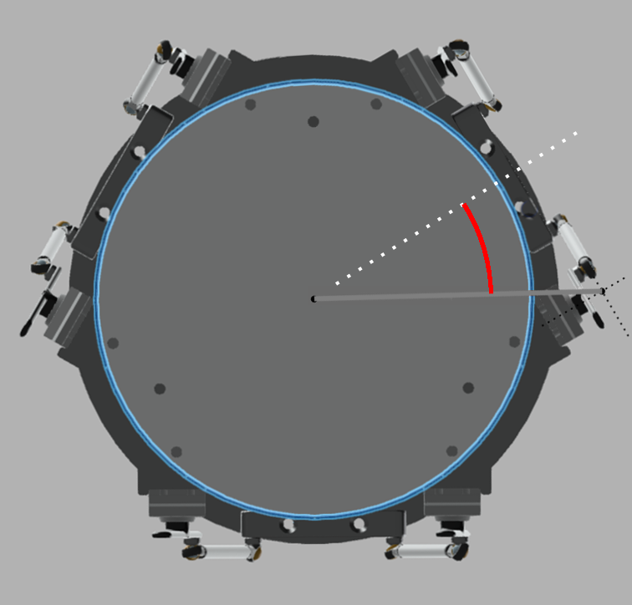
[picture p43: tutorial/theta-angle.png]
Angle between axis and servo/control rod connection


Angle (THETA) between paired servo arm pivot points (BASE)

Defaults to 55.36°

## THETA_EFFECTOR

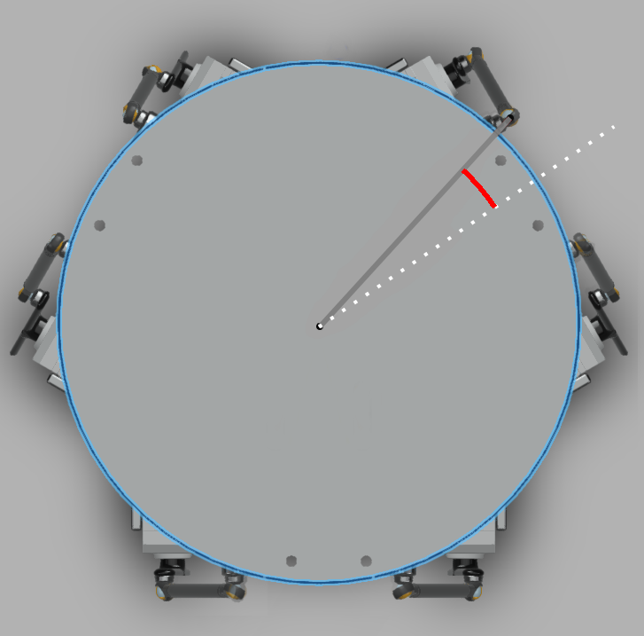
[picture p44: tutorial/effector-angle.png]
Angle between axis and control rod platform connection


Angle (THETA) between paired effector attachment points (EFFECTOR)

Defaults to 30.75°

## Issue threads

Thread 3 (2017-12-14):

Add dimension callouts on top and bottom platform PDFs

jketreno, 2017-12-14:
The top and bottom PDF files should have dimensional callouts for relevant angles and distances, allowing someone to create the platform holes without using using a printed trace template.

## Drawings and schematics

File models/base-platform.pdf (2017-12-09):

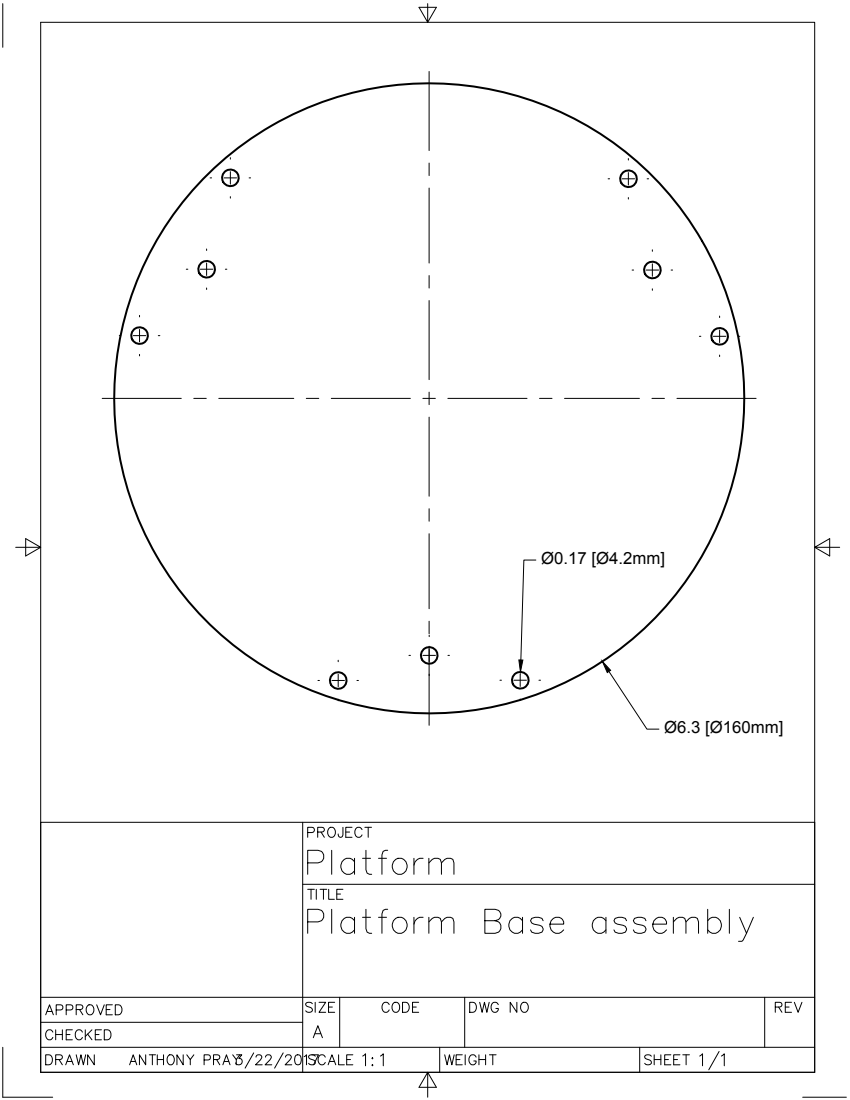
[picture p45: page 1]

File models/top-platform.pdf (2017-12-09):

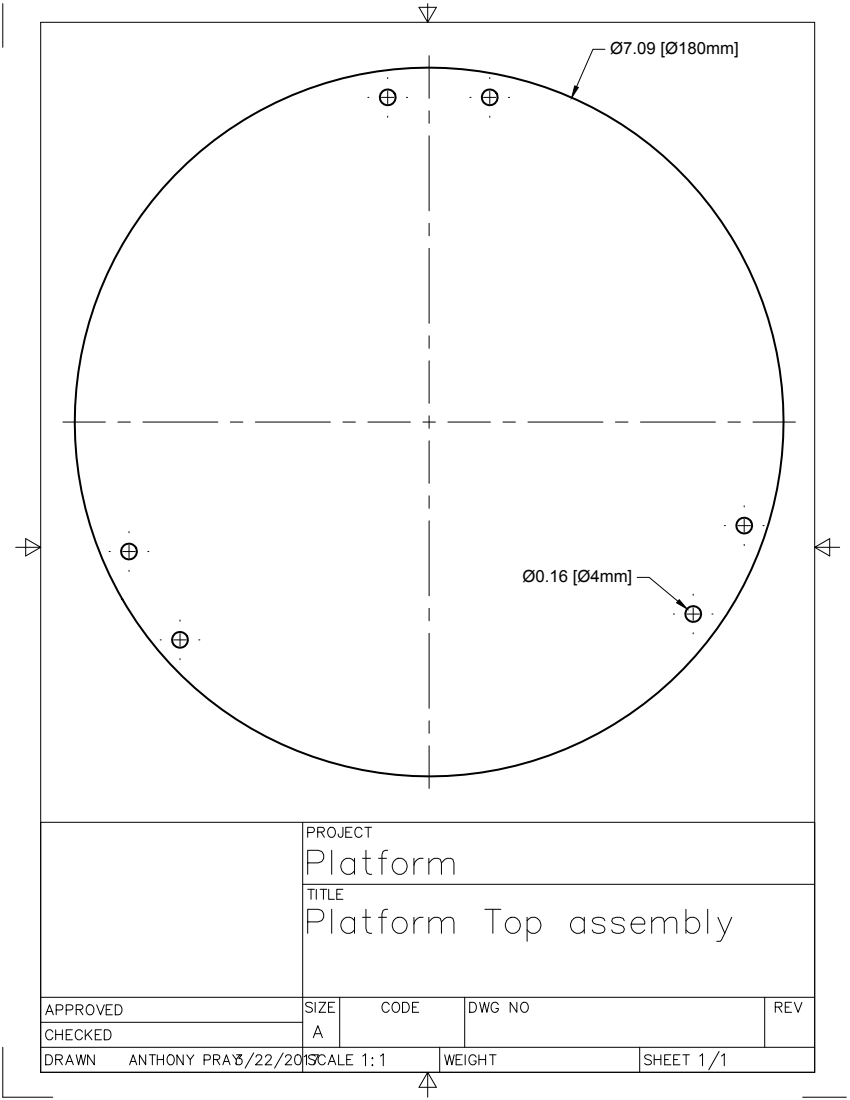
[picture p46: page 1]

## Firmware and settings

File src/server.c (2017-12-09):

/*
 * Copyright (c) 2015-2017, Intel Corporation.
 *
 * This program is licensed under the terms and conditions of the
 * Apache License, version 2.0.  The full text of the Apache License is at
 * http://www.apache.org/licenses/LICENSE-2.0
 *
 */
#include <errno.h>
#include <fcntl.h>
#include <ifaddrs.h>
#include <math.h>
#include <netdb.h>
#include <poll.h>
#include <stdio.h>
#include <stdlib.h>
#include <string.h>
#include <unistd.h>

#include <arpa/inet.h>

#include <linux/limits.h>

#include <netinet/in.h>

#include <sys/socket.h>
#include <sys/stat.h>
#include <sys/time.h>
#include <sys/types.h>

#include "pca9685.h"

#include "stewart.h"
#include "config.h"
#include "stewart-pubsub.h"
#include "delay.h"

int quiet = 0;

#define MAX_CONNECTIONS 11 /* 10 CLIENTs, and 1 SERVER */
struct pollfd fds[MAX_CONNECTIONS];
char buffer[MAX_CONNECTIONS][sizeof(StewartMessage) * 2];
int bufferIndex[MAX_CONNECTIONS];
StewartMessage pending[MAX_CONNECTIONS];
Transform transform;

float origin[3] = { 0, 0, 0 };
Solution solutions[6];
float rotationMatrix[9];

void usage(int ret) {
    fprintf(stderr, "usage: server -p PORT [-i INTERFACE]\n"
            "\n"
            "-p PORT       Listen on PORT for socket connections\n"
            "-i INTERFACE  Bind to INTERFACE to listen accept connections\n"
            "-q            Quiet. Supress transform output.\n"
            "-d            Debug. Turn on Stewart platform debug information (if local)\n"
            "-s            Simulate. Don't try and connect to the PCA9685.\n"
            "-?            Help\n"
            "-v            Version\n"
            "\n"
            "See PROTOCOL for details on the Stewart platform protocol.\n");
    exit(ret);
}

void version() {
    fprintf(stdout,
            "server: Stewart platform server control\n"
            "Copyright (C) 2017 Intel Corporation\n"
            "Licensed under the terms of the Apache 2.0 license. See LICENSE file.\n"
            "\n"
            "Version: " VERSION "\n");
    exit(0);
}

int init_platform(StewartConfig *config, PCA9685 **pca, StewartPlatform ** platform) {
    int err = 0;

    /* Initialize the default values for the Stewart platform as
     * documented at https://01.org/developerjourney/recipe/stewert-platform */
    config_get(config);

    /* Create the Stewart platform solver as configured */
    *platform = stewart_platform_create(config);
    if (!*platform) {
        fprintf(stderr, "Could not create a Stewart platform solver!\n");
        return -1;
    }

    if (config->debug) {
        stewart_platform_dump(*platform);
    }

    /* If pca == NULL then this is a simulator; don't connect to the PCA9685 */
    if (pca) {
        /* Attempt to connect to PCA9685 in order to program the servo locations */
        *pca = pca9685_open(0, 0x40);
        if (!*pca) {
            fprintf(stderr, "Could not initialize PCA9685!\n");
            err = -2;
            goto terminate;
        }

        err = pca9685_set_pulse_frequency(*pca, PULSE_WIDTH_FREQUENCY);
        if (err) {
            fprintf(stderr, "Could not set PWM frequency!\n");
            err = -3;
            goto terminate;
        }
    }

    return 0;

terminate:
    if (*platform) {
        stewart_platform_delete(*platform);
        *platform = NULL;
    }

    if (pca && *pca) {
        pca9685_close(*pca);
        *pca = NULL;
    }

    return err;
}

void getStatus(StewartConfig *config, StewartPlatform *platform, StewartStatus *status) {
    struct timeval elapsed;
    int i;

    memset(status, 0, sizeof(*status));

    elapsed = stewart_platform_get_elapsed(platform);
    status->sec = elapsed.tv_sec;
    status->usec = elapsed.tv_usec;

    for (i = 0; i < 6; i++) {
        status->servos[i].angle = solutions[i].angle;
        status->servos[i].trim = config->servo_trim[i];
    }

    memcpy(status->origin, origin, sizeof(origin));
    memcpy(status->rotation, rotationMatrix, sizeof(rotationMatrix));
}

void processMessage(StewartConfig *config, StewartPlatform *platform, PCA9685 *pca, int index, const StewartMessage *message) {
    static long now = 0;
    static long then = 0;
    struct timeval tv;
    int i;
    Point _origin = { .x = origin[0], .y = origin[1], .z = origin[2] };

    if (message->version != STEWART_PROTOCOL ||
        message->size != sizeof(*message)) {
        fprintf(stdout, "Invalid message received %d %d.\n", message->version, message->size);
        return;
    }

    switch (message->type) {
        case STEWART_MESSAGE_SET_AXISANGLE:
            memset(&transform, 0, sizeof(transform));

            fprintf(stdout, "Axis-Angle: <%+.02f, %+.02f, %+.02f>, Angle: %+.02fdeg\n",
                    message->axisAngle.x, message->axisAngle.y, message->axisAngle.z,
                    message->axisAngle.angle);
            fprintf(stdout, "Translation: <X: %+.02f, Y: %+.02f, Z: %+.02f>\n",
                    message->axisAngle.translate.x,
                    message->axisAngle.translate.y,
                    message->axisAngle.translate.z);

            transform.type = TRANSFORM_AXIS_ANGLE;
            transform.rotate.x = message->axisAngle.x;
            transform.rotate.y = message->axisAngle.y;
            transform.rotate.z = message->axisAngle.z;
            transform.angle = message->axisAngle.angle;
            transform.translate.x = message->axisAngle.translate.x;
            transform.translate.y = message->axisAngle.translate.y;
            transform.translate.z = message->axisAngle.translate.z;

            break;

        case STEWART_MESSAGE_SET_EUCLIDEAN:
            memset(&transform, 0, sizeof(transform));

            fprintf(stdout, "Rotation: <Roll: %+.02f, Pitch: %+.02f, Yaw: %+.02f>\n",
                    message->euclidean.roll,
                    message->euclidean.pitch,
                    message->euclidean.yaw);
            fprintf(stdout, "Translation: <X: %+.02f, Y: %+.02f, Z: %+.02f>\n",
                    message->euclidean.translate.x,
                    message->euclidean.translate.y,
                    message->euclidean.translate.z);

            transform.type = TRANSFORM_EUCLIDEAN;
            transform.rotate.x = message->euclidean.pitch;
            transform.rotate.y = message->euclidean.yaw;
            transform.rotate.z = message->euclidean.roll;
            transform.translate.x = message->euclidean.translate.x;
            transform.translate.y = message->euclidean.translate.y;
            transform.translate.z = message->euclidean.translate.z;
            break;

        case STEWART_MESSAGE_SET_TRIM:
            if (!quiet) {
                fprintf(stdout, "Setting trim %d = %+5.02fdeg\n",
                        message->trim.servo, message->trim.angle);
            }
            if (message->trim.servo >= 0 && message->trim.servo <= 5) {
                config->servo_trim[message->trim.servo] = message->trim.angle;
                config_write(config);
            }
            /* Fall through to set the servos to their value based on the new
             * trim values */
            break;

        case STEWART_MESSAGE_GET_STATUS:
            if (!quiet) {
                fprintf(stdout, "Status requested. Sending...\n");
            }
            memset(&pending[index], 0, sizeof(pending[index]));
            pending[index].type = STEWART_MESSAGE_STATUS;
            pending[index].version = STEWART_PROTOCOL;
            pending[index].size = sizeof(pending[index]);
            getStatus(config, platform, &pending[index].status);
            fds[index].events |= POLLOUT;
            return;

        default:
            fprintf(stderr, "Warning: Invalid message type: %d\n", message->type);
            return;
    }

    stewart_get_solutions(platform, &_origin, &transform, solutions, rotationMatrix);

    int constrained = 0;
    for (i = 0; i < 6; i++) {
        const char *type = "UNKNOWN";

        switch (solutions[i].type & MASK) {
            case SOLUTION:
                if (solutions[i].type & LIMITED) {
                    type = "LIMITED";
                    constrained++;
                } else {
                    type = "SOLUTION";
                }
                break;
            case IMPOSSIBLE:
                type = "IMPOSSIBLE";
                constrained++;
                break;
            default:
                fprintf(stderr, "Error: Invalid solution type: %d\n", solutions[i].type);
                break;
        }

        if (!quiet) {
            fprintf(stdout, "Servo %d: %.02fdeg [%s]\n", i, solutions[i].angle, type);
        }
    }

    /* Only output to the PWM once per cycle */
    gettimeofday(&tv, NULL);
    now = tv.tv_sec * 1000 + tv.tv_usec / 1000;
    if (now - then < 1000 / PULSE_WIDTH_FREQUENCY) {
        delay(1000 * (1000 / PULSE_WIDTH_FREQUENCY - (now - then)));
    }
    then = now;

    /* Send servo positions to servos */
    if (pca) {
        for (i = 0; i < 6; i++) {
            pca9685_set_channel_pulse(
                pca, i, 0, RADIANS_TO_PULSE_WIDTH(DEG2RAD(solutions[i].angle)));
        }
    }
}

int main(int argc, char *argv[]) {
    PCA9685 *pca = NULL;
    StewartConfig _c;
    StewartConfig *config = &_c;
    StewartPlatform *platform = NULL;
    int err = 0;
    int sock = -1;
    int i, port = -1;
    char *iface = "lo";
    int simulate = 0;
    int ret;

    struct ifaddrs *ifaddr = NULL, *p;
    char hostIpAddr[NI_MAXHOST];

    config->debug = 0;

    for (i = 1; i < argc; i++) {
        if (argv[i][0] == '-') {
            switch (argv[i][1]) {
                case 's':
                    simulate = 1;
                    break;

                case 'p': /* next is port */
                    i++;
                    if (i >= argc) {
                        usage(-1);
                    }
                    port = strtol(argv[i], NULL, 0);
                    break;
                case 'q':
                    quiet = 1;
                    break;
                case 'd':
                    config->debug = 1;
                    break;

                case '?':
                    usage(0);
                    break;
                case 'v':
                    version();
                    break;
                case 'i':
                    i++;
                    if (i >= argc) {
                        usage(-1);
                    }
                    iface = argv[i];
                    break;
            }
        }
    }

    if (port == -1) {
        usage(-1);
    }

    if (!quiet && simulate) {
        fprintf(stdout, "Simulating PCA9685.\n");
    }

    if (init_platform(config, simulate ? NULL : &pca, &platform)) {
        fprintf(stderr, "Error: Unable to initializing Stewart platform.\n");
        return -1;
    }

    sock = socket(AF_INET, SOCK_STREAM, IPPROTO_TCP);

    if (sock == -1) {
        fprintf(stderr, "Error: Unable to create socket: %s\n", strerror(errno));
        goto terminate;
    }

    if (iface != NULL && !quiet) {
        fprintf(stdout, "Interface: %s\n", iface);
    }

    if (port && !quiet) {
        fprintf(stdout, "Port: %d\n", port);
    }

    if (getifaddrs(&ifaddr) == -1) {
        fprintf(stderr, "Error: Unable to query for interface names: %s", strerror(errno));
        goto terminate;
    }

    for (p = ifaddr; p; p = p->ifa_next) {
        if (!p->ifa_addr ||
            (p->ifa_addr->sa_family != AF_INET) ||
            strcmp(p->ifa_name, iface)) {
            continue;
        }
        err = getnameinfo(p->ifa_addr, sizeof(*p->ifa_addr),
                          hostIpAddr, sizeof(hostIpAddr), NULL, 0, NI_NUMERICHOST);
        if (err != 0) {
            fprintf(stderr, "Error: Unable to get interface names: %s", strerror(errno));
            freeifaddrs(ifaddr);
            goto terminate;
        }

        break;
    }
    freeifaddrs(ifaddr);
    if (p == NULL) {
        fprintf(stderr, "Error: Unable to find interface %s.\n", iface);
        goto terminate;
    }

    if (!quiet) {
        fprintf(stdout, "Binding to %s: %s:%d\n", iface, hostIpAddr, port);
    }

    int enable = 1;
    if (setsockopt(sock, SOL_SOCKET, SO_REUSEADDR, &enable, sizeof(enable)) < 0) {
        fprintf(stderr, "Error: Unable to SO_REUSEADDR: %s\n", strerror(errno));
        goto terminate;
    }

    struct sockaddr_in sin;
    sin.sin_port = htons(port);
    sin.sin_family = AF_INET;
    inet_aton(hostIpAddr, &sin.sin_addr);
    if (bind(sock, (struct sockaddr *)&sin, sizeof(sin)) == -1) {
        fprintf(stderr, "Error: Unable to bind to %s: %s:%d:\n%s\n",
                iface, hostIpAddr, port, strerror(errno));
        goto terminate;
    }

    fcntl(sock, F_SETFL, O_NONBLOCK);

    if (listen(sock, 10) == -1) {
        fprintf(stderr, "Error: Unable to listen on socket: %s\n",
                   strerror(errno));
        goto terminate;
    }

    fds[0].fd = sock;
    fds[0].events = POLLIN;
    for (i = 1; i < sizeof(fds) / sizeof(fds[0]); i++) {
        fds[i].fd = -1;
    }
    int maxIndex = 1;

    while (1) {
        if (!quiet) {
            fprintf(stderr, "Listening to connections %d for data and for new connections.\n", maxIndex);
        }

        int resCount = poll(fds, maxIndex, -1);
        if (resCount == -1) {
            fprintf(stderr, "Error: Poll returned an error: %s\n", strerror(errno));
            goto terminate;
        }

        /* Check the LISTEN socket for new connections */
        if (fds[0].revents & POLLIN) {
            resCount--;

            /* socket accept is ready! */
            struct sockaddr_in peerAddr;
            socklen_t peerAddrSize = sizeof(peerAddr);
            int peer;
            while (1) {
                peer = accept(fds[0].fd, (struct sockaddr *)&peerAddr, &peerAddrSize);
                if (peer == -1 && errno == EAGAIN) {
                    break;
                }
                if (peer == -1) {
                    fprintf(stderr, "Error: Unable to accept connect: %s\n",
                        strerror(errno));
                    goto terminate;
                }

                if (!quiet) {
                    fprintf(stdout, "Connection from %s on %d (%d)\n",
                            inet_ntoa(peerAddr.sin_addr), ntohs(peerAddr.sin_port), peer);
                }

                if (maxIndex == MAX_CONNECTIONS) {
                    fprintf(stderr, "Error: Too many connections. Closing new connection.\n");
                    close(peer);
                    continue;
                }

                fcntl(peer, F_SETFL,  O_NONBLOCK);

                fds[maxIndex].fd = peer;
                fds[maxIndex].events = POLLIN | POLLHUP | POLLNVAL | POLLERR;
                fds[maxIndex].revents = 0;
                bufferIndex[maxIndex] = 0;
                pending[maxIndex].type = STEWART_MESSAGE_INVALID;
                memset(buffer[maxIndex], 0, sizeof(buffer[maxIndex]));

                maxIndex++;
            }
        }

        if (!quiet) {
            fprintf(stderr, "Checking %d sockets for data.\n", maxIndex - 1);
        }

        int collapseTo = 0;

        /* Loop through all of the watched sockets until resCount descriptors
         * have been handled */
        for (i = 1; i < maxIndex && resCount > 0; i++) {
            if (fds[i].revents) {
                resCount--;
            }

            if (fds[i].revents & POLLIN) {
                while (1) {
                    ret = recv(fds[i].fd, buffer[i] + bufferIndex[i], sizeof(StewartMessage), MSG_DONTWAIT);
                    if (ret == -1 && (errno == EAGAIN || errno == EWOULDBLOCK)) {
                        break;
                    }

                    if (ret == 0) {
                        fprintf(stdout, "Socket disconnected.\n");
                        close(fds[i].fd);
                        fds[i].fd = -1;
                        fds[i].events = fds[i].revents = 0;
                        bufferIndex[i] = 0;
                        /* If an array collapse isn't already occurring, start collapsing
                         * to replace this now unused slot */
                        if (!collapseTo) {
                            collapseTo = i;
                        }
                        break;
                    }

                    if (!quiet) {
                        fprintf(stdout, "%d bytes received. Waiting for at least %ld\n", ret, sizeof(StewartMessage));
                    }

                    bufferIndex[i] += ret;
                    if (bufferIndex[i] >= sizeof(StewartMessage)) {
                        if (!quiet) {
                            fprintf(stdout, "Message received with %d bytes (%zu remaining.)\n",
                                   bufferIndex[i], bufferIndex[i] - sizeof(StewartMessage));
                        }
                        bufferIndex[i] -= sizeof(StewartMessage);
                        processMessage(config, platform, pca, i, (StewartMessage *)buffer[i]);
                        memcpy(buffer[i], &buffer[i][sizeof(StewartMessage)], bufferIndex[i]);
                    }
                }
            }

            if (fds[i].revents & POLLOUT) {
                if (!quiet) {
                    fprintf(stdout, "Data OUT ready %d\n", fds[i].fd);
                }
                if (pending[i].type != STEWART_MESSAGE_INVALID) {
                    ret = send(fds[i].fd, &pending[i], sizeof(pending[i]), MSG_DONTWAIT);
                    if (ret == -1 && (errno == EAGAIN || errno == EWOULDBLOCK)) {
                        break;
                    }
                    if (ret != sizeof(pending[i])) {
                        /* If this gets triggered, then we need to start tracking how many
                         * bytes of the packet *were* sent and continue sending the data
                         * message until the entire frame is sent. This shouldn't trigger
                         * so long as the payload is less than a TCP packet size */
                        fprintf(stderr, "Error: Sending did not transmit entire block!\n");
                        goto terminate;
                    }
                }
                fds[i].events &= ~POLLOUT;
            }

            if (fds[i].revents & (POLLHUP | POLLNVAL | POLLERR)) {
                fprintf(stdout, "Socket error and disconnect.\n");
                close(fds[i].fd);
                fds[i].fd = -1;
                fds[i].events = fds[i].revents = 0;
                bufferIndex[i] = 0;
                /* If an array collapse isn't already occurring, start collapsing
                 * to replace this now unused slot */
                if (!collapseTo) {
                    collapseTo = i;
                }
            }

            if (collapseTo && fds[i].fd != -1) {
                /* If a collapse is occurring, copy the current fd into the
                 * collapse target, and advance the target */
                fds[collapseTo++] = fds[i];
            }
        }

        /* The array was being collapsed and all events were processed, so complete
         * collapsing the array */
        while (i < maxIndex && collapseTo != 0) {
            memcpy(buffer[collapseTo], buffer[i], bufferIndex[i]);
            fds[collapseTo++] = fds[i];
            i++;
        }

        if (collapseTo) {
            maxIndex = collapseTo;
        }
    }

    err = 0;

terminate:
    if (sock != -1) {
        close(sock);
    }

    if (platform) {
        stewart_platform_delete(platform);
    }

    if (pca) {
        pca9685_close(pca);
    }

    return err;
}

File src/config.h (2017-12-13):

/*
 * Copyright (c) 2015-2017, Intel Corporation.
 *
 * This program is licensed under the terms and conditions of the
 * Apache License, version 2.0.  The full text of the Apache License is at
 * http://www.apache.org/licenses/LICENSE-2.0
 *
 */
#ifndef __config_h__
#define __config_h__

#include "stewart.h"

/***************************************************************************
 *
 * The files in this project requires that servos be arranged
 * as documented in the Developer Journey [1] with the PWM channel 0
 * corresponding to servo 0:
 *
 *                               y+
 *                                ^
 *                                |
 *                            .-------.
 *                         2 /         \ 3
 *                          /           \
 *                       1 /             \ 4
 *                -x <--- <       o +z    >  ---> x+
 *                         \             /
 *                          \           /
 *                           \         /
 *                            `-------'
 *                              0 | 5
 *                                v
 *                               -y
 *
 * 1. https://01.org/developerjourney/recipe/stewart-platform
 *
 ***************************************************************************/

/* Trim amount in DEGREES to adjust the servo so that zero degrees is
 * indeed zero. See "trim" application and "stewart.cfg" to keep from needing
 * to modify this file  */
#define TRIM_0            0
#define TRIM_1            0
#define TRIM_2            0
#define TRIM_3            0
#define TRIM_4            0
#define TRIM_5            0

/* Min and Max PWM signals for Tower Pro SG-5010 */
#define SERVO_MIN_ANGLE       -90     /* For 180-degree servo */
#define SERVO_MAX_ANGLE       +90     /* For 180-degree servo */
#define PULSE_WIDTH_MAX_POS   2500    /* in us - ~2500 is "standard" */
#define PULSE_WIDTH_MIN_POS   500     /* in us - ~500 is "standard"  */
#define PULSE_WIDTH_FREQUENCY 100     /* in Hz - cycles per second   */
#define PULSE_WIDTH_ZERO_POS  1500    /* in ms - ~1500 is "standard" */

/***************************************************************************
 *
 * If you build to the dimensions specified in the Developer Journey,
 * then you shouldn't need to modify any of the values below.
 *
 ***************************************************************************/

/* Servo external physical limits (0 is horizontal) -- change these values
 * based on if your servos are binding or running into things when they move */
#define SERVO_MIN          -85
#define SERVO_MAX          +85

/* Servo arm length in inches from center to ball joint pivot */
#define SERVO_ARM_LENGTH   (float)(1.0f + 7.0f / 16.0f)

/* Control rod length in inches */
#define CONTROL_ROD_LENGTH (float)(4.0f + 1.0f / 16.0f)

/* With servos at 0 position, vertical distance from link top to servo axis
 * This is used as Z coordinate in the effector_pos */
#define PLATFORM_HEIGHT    (float)(3.0f + 5.0f / 16.0f)

/* Center of top platform to effector connector in inches */
#define EFFECTOR_RADIUS    (float)(3.949f)

/* Center of base platform to pivot of servo arm in inches */
#define BASE_RADIUS        (float)(3.0f + 13.0f / 16.0f)

/* Angle (THETA) between paired servo arm pivot points (BASE)
 * IN RADIANS */
#define THETA_BASE         DEG2RAD(55.36f)

/* Angle (THETA) between paired effector attachement points (EFFECTOR)
 * IN RADIANS */
#define THETA_EFFECTOR     DEG2RAD(30.75f)

/* Max angles to allow the platform to attempt to move within */
#define MAX_ROLL      (15.0f)
#define MAX_PITCH     (15.0f)
#define MAX_YAW       (30.0f)

/************************************************************************
 *
 * You should not need to change anything below this line unless
 * you build a layout of the Stewart platform different than is
 * documented in the Developer Journey.
 *
 * For example, if you change how the servos are rotated relative to the
 * effector positions, or use servos that rotate in the opposite direction
 * from the servos in the Developer Journey.
 *
 *************************************************************************/

/* Rotation IN RADIANS of the positive (left-hand rule) axis for the servo
 * relative to the platform Z axis */
#define SERVO_ORIENTATION_0 ( 6.0 * M_PI / 6.0)
#define SERVO_ORIENTATION_1 (-4.0 * M_PI / 6.0)
#define SERVO_ORIENTATION_2 ( 2.0 * M_PI / 6.0)
#define SERVO_ORIENTATION_3 ( 4.0 * M_PI / 6.0)
#define SERVO_ORIENTATION_4 (-2.0 * M_PI / 6.0)
#define SERVO_ORIENTATION_5 ( 0.0 * M_PI / 6.0)

/* Direction the servo rotates to move the servo arm in the positive
 * Z direction */
#define SERVO_DIRECTION_0   CLOCKWISE
#define SERVO_DIRECTION_1   COUNTER_CLOCKWISE
#define SERVO_DIRECTION_2   CLOCKWISE
#define SERVO_DIRECTION_3   COUNTER_CLOCKWISE
#define SERVO_DIRECTION_4   CLOCKWISE
#define SERVO_DIRECTION_5   COUNTER_CLOCKWISE
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

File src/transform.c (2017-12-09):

/*
 * Copyright (c) 2015-2017, Intel Corporation.
 *
 * This program is licensed under the terms and conditions of the
 * Apache License, version 2.0.  The full text of the Apache License is at
 * http://www.apache.org/licenses/LICENSE-2.0
 *
 */
#include <errno.h>
#include <fcntl.h>
#include <math.h>
#include <netdb.h>
#include <stdio.h>
#include <stdlib.h>
#include <string.h>
#include <unistd.h>

#include <arpa/inet.h>

#include <linux/limits.h>

#include <sys/socket.h>
#include <sys/stat.h>
#include <sys/time.h>
#include <sys/types.h>

#include "pca9685.h"

#include "stewart.h"
#include "stewart-pubsub.h"
#include "config.h"
#include "delay.h"

void usage(int ret) {
    fprintf(stderr,
            "usage: transform [OPTIONS] [TRANSFORM]\n"
            "\n"
            "If not supplied on the command line, the TRANSFORM value is read\n"
            "from STDIN, one line at a time.\n"
            "\n"
            "TRANSFORM can be of the form:"
            "axis-angle:\n"
            "    axis-x axis-y axis-z angle-in-degrees [TRANSLATE]\n"
            "euclidian:\n"
            "    roll pitch yaw translate-x translate-y translate-z [ORIGIN]\n"
            "\n"
            "ORIGIN is optional and specifies the coordinates to use as the origin\n"
            "for the transformation."
            "\n"
            "Options:\n"
            "-s            Simulate. Do not connect to PCA9685.\n"
            "-q            Quiet. Supress transform output.\n"
            "-d            Debug. Turn on Stewart platform debug information\n"
            "              (if local)\n"
            "-h HOST:PORT  Connect to Stewart platform on HOST:PORT\n"
            "\n"
            "If -s is not provided, transform will attempt to connect to a\n"
            "Stewart platform on i2c bus.\n\n");
    exit(ret);
}

void version() {
    fprintf(stdout,
            "transform: Stewart platform set-transform application\n"
            "Copyright (C) 2017 Intel Corporation\n"
            "Licensed under the terms of the Apache 2.0 license. See LICENSE file.\n"
            "\n"
            "Version: " VERSION "\n");
    exit(0);
}

int set_transform(const float *params, int param_count, Transform *transform, Point *origin) {
  switch (param_count) {
    case 4: /* axis-angle */
    case 7: /* axis-angle + origin */
      transform->type = TRANSFORM_AXIS_ANGLE;

      /* Roll (X-axis), Pitch (Y-axis), Yaw (Z-axis) */
      transform->rotate.x = params[0];
      transform->rotate.y = params[1];
      transform->rotate.z = params[2];

      transform->angle = params[3];
      memset(origin, 0, sizeof(*origin));
      if (param_count == 7) {
        transform->translate.x = params[4];
        transform->translate.y = params[5];
        transform->translate.z = params[6];
      } else {
        memset(&transform->translate, 0, sizeof(transform->translate));
      }
      return 0;

    case 6: /* euler angle */
    case 9: /* euler angle + origin */
      transform->type = TRANSFORM_EUCLIDEAN;

      /* Roll (X-axis), Pitch (Y-axis), Yaw (Z-axis) */
      transform->rotate.x = params[0];
      transform->rotate.y = params[1];
      transform->rotate.z = params[2];
      /* Roll (X-axis), Pitch (Y-axis), Yaw (Z-axis) */
      transform->translate.x = params[3];
      transform->translate.y = params[4];
      transform->translate.z = params[5];
      if (param_count == 9) {
        origin->x = params[6];
        origin->y = params[7];
        origin->z = params[8];
      } else {
        memset(origin, 0, sizeof(*origin));
      }
      return 1;

    default:
      return -1;
    }
}

int main(int argc, char *argv[]) {
    PCA9685 *pca = NULL;
    StewartConfig config = {
      .debug = 0
    };
    StewartPlatform *platform = NULL;
    int err = 0;
    int i;
    int use_stdin = 1; /* read from stdin for commands */
    const int ERR = 16384;
    int port;
    char *host = NULL;
    int sock = -1;
    int simulate = 0;
    int quiet = 0;
    int euler = 0;
    float *params = NULL;
    int param_count = 0;

    /* Solve for the solution angles for the given platform transform */
    Solution solutions[6];

    Transform transform = {
        .type = TRANSFORM_AXIS_ANGLE,
        .angle = ERR,
        .rotate = {
            .x = ERR,
            .y = ERR,
            .z = ERR
        },
        .translate = {
            .x = ERR,
            .y = ERR,
            .z = ERR
        }
    };
    Point origin = {
        .x = ERR,
        .y = ERR,
        .z = ERR
    };

    params = (float *)malloc(sizeof(float *) * argc);

    /* Parse command line arguments... */
    for (i = 1; i < argc; i++) {
        if (argv[i][0] != '-' || !(argv[i][1] < '0' || argv[i][1] > '9')) {
            params[param_count++] = strtof(argv[i], NULL);
            continue;
        }

        switch (argv[i][1]) {
            case '?':
                usage(0);
                break;

            case 'd':
                config.debug = 1;
                break;

            case 'q':
                quiet = 1;
                break;

            case 's':
                simulate = 1;
                break;

            case 'h':
                i++;
                if (i == argc) {
                    fprintf(stderr, "Invalid argument %d: %s", i, argv[i]);
                    usage(-1);
                }
                char *colon = strchr(argv[i], ':');
                if (!colon) {
                    fprintf(stderr, "Invalid argument %d: %s", i, argv[i]);
                    usage(-1);
                }
                *colon = '\0';
                colon++;
                host = argv[i];
                port = strtol(colon, NULL, 0);
                break;

            case 'v':
                version();
                break;

            default:
                usage(-1);
                break;
        }
    }

    /* Process parameters provided on command line */
    if (param_count == 0) {
        use_stdin = 1;
    } else {
      switch (set_transform(params, param_count, &transform, &origin)) {
        case 0: /* axis-angle */
          euler = 0;
          break;
        case 1: /* euler */
          euler = 1;
          break;
        case -1: /* error */
        default:
          usage(-1);
          break;
      }
    }

    if (!quiet) {
        fprintf(stdout, "Stewart platform transform\n"
                "Copyright (C) 2015-2017 Intel Corporation\n\n");
    }

    if (!quiet) {
        if (use_stdin) {
            fprintf(stdout, "Reading from STDIN\n");
        } else {
            fprintf(stdout, "Executing %s transform from command line.\n",
                    euler ? "EULER" : "AXIS-ANGLE");
        }
    }
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

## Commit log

2017-12-09 Initial version published for Developer Journey article
    [ServoArm.stl, ServoMount.stl, TopMount.stl]
2017-12-12 Updated tutorial with more obvious STL links
2017-12-12 Remove step numbers; let it auto-number
    Removed price estimate on PLA printing
2017-12-12 Rephrased the $ saved by printing your own 3D parts
2017-12-13 Use Gyro on PS3 controller
2017-12-13 Updated dimensions in tutorial and added notes about lock nut spacers.
